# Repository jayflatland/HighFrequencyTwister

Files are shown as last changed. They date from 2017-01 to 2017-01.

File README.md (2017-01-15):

# HighFrequencyTwister
These are all the source code and design files for High Frequency Twister, the Rubik's Cube solving robot built by Jay Flatland and Paul Rose that set the World Record at 0.900s on February 5, 2016.

Primary files include:
* FreeCAD drawings for 3D printed parts
* Arduino sketch for stepper motor controller
* C++ code for the solving application
* Various other cruft we collected along the way

The code is a mess, but it got the job done.  We meant to organize this better before releasing, but never got around to it and decided to just publish it as-is rather than delaying any more.

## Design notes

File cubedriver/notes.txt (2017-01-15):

ThreadSolver2 - nkclintrade, goal 887ms, target 887ms, speed 5 (more), 8 threads, 0,LR90,FB90,D1,L1,R1,L3,B3,B1,F1,D3,U3,U1,R3,F3,F2,D2,R2,L2,B2,U2
Runs: 1000
Fails: 0
avgSolveTime:    40.488ms
avgMovesTime:   797.816ms
avgTotalTime:   838.304ms
WithCamTime:    898.304ms
movesTimeHistogram:
600,32,3%
700,428,43%
800,534,53%
900,6,1%
underGoalHistogram: 887ms
0,355,36%
1000,645,64%
solutionIdxHistogram:
0,208,21%
1,211,21%
2,216,22%
3,97,10%
4,76,8%
5,50,5%
6,69,7%
7,73,7%

ThreadSolver2 - nkclintrade, goal 887ms, target 887ms, speed 5, 8 threads, 0,LR90,FB90,D1,L1,R1,L3,B3,B1,F1,D3,U3,U1,R3,F3,F2,D2,R2,L2,B2,U2
Runs: 1000
Fails: 0
avgSolveTime:    40.928ms
avgMovesTime:   823.402ms
avgTotalTime:   864.330ms
WithCamTime:    924.330ms
movesTimeHistogram:
600,18,2%
700,292,29%
800,659,66%
900,31,3%
underGoalHistogram: 887ms
0,201,20%
1000,799,80%
solutionIdxHistogram:
0,208,21%
1,211,21%
2,216,22%
3,97,10%
4,76,8%
5,50,5%
6,69,7%
7,73,7%

ThreadSolver2 - nkclintrade, goal 887ms, target 887ms, speed 4, 8 threads, 0,LR90,FB90,D1,L1,R1,L3,B3,B1,F1,D3,U3,U1,R3,F3,F2,D2,R2,L2,B2,U2
Runs: 1000
Fails: 0
avgSolveTime:    40.722ms
avgMovesTime:   859.545ms
avgTotalTime:   900.267ms
WithCamTime:    960.267ms
movesTimeHistogram:
600,5,0%
700,120,12%
800,656,66%
900,219,22%
underGoalHistogram: 887ms
0,129,13%
1000,871,87%
solutionIdxHistogram:
0,211,21%
1,215,22%
2,212,21%
3,97,10%
4,72,7%
5,51,5%
6,69,7%
7,73,7%

ThreadSolver2 - nkclintrade, goal 887ms, target 850ms, speed 4, 8 threads, 0,LR90,FB90,D1,L1,R1,L3,B3,B1,F1,D3,U3,U1,R3,F3,F2,D2,R2,L2,B2,U2
Runs: 1000
Fails: 0
avgSolveTime:    40.572ms
avgMovesTime:   859.194ms
avgTotalTime:   899.766ms
WithCamTime:    959.766ms
movesTimeHistogram:
600,5,0%
700,123,12%
800,653,65%
900,219,22%
underGoalHistogram: 887ms
0,92,9%
1000,908,91%
solutionIdxHistogram:
0,208,21%
1,211,21%
2,214,21%
3,98,10%
4,77,8%
5,50,5%
6,69,7%
7,73,7%

ThreadSolver2 - nkclintrade, goal 887ms, target 850ms, speed 4, 4 threads, 0,LR90,FB90,D1,L1,R1,L3,B3,B1,F1,D3,U3,U1,R3,F3,F2,D2,R2,L2,B2,U2
Runs: 1000
Fails: 0
avgSolveTime:    29.807ms
avgMovesTime:   873.162ms
avgTotalTime:   902.969ms
WithCamTime:    962.969ms
movesTimeHistogram:
600,3,0%
700,98,10%
800,564,56%
900,328,33%
1000,7,1%
underGoalHistogram: 887ms
0,97,10%
1000,903,90%
solutionIdxHistogram:
0,294,29%
1,285,28%
2,299,30%
3,122,12%

ThreadSolver2 - nkclintrade, goal 887ms, target 800ms, speed 4, 4 threads, 0,LR90,FB90,D1,L1,R1,L3,B3,B1,F1,D3,U3,U1,R3,F3,F2,D2,R2,L2,B2,U2
Runs: 1000
Fails: 0
avgSolveTime:    29.822ms
avgMovesTime:   873.120ms
avgTotalTime:   902.942ms
WithCamTime:    962.942ms
movesTimeHistogram:
600,3,0%
700,98,10%
800,564,56%
900,328,33%
1000,7,1%
underGoalHistogram: 887ms
0,99,10%
1000,901,90%
solutionIdxHistogram:
0,293,29%
1,285,28%
2,300,30%
3,122,12%

ThreadSolver2 - nkclintrade, goal 887ms, target 100ms, speed 4, 4 threads, 0,LR90,FB90,D1,L1,R1,L3,B3,B1,F1,D3,U3,U1,R3,F3,F2,D2,R2,L2,B2,U2
Runs: 1000
Fails: 0
avgSolveTime:    29.509ms
avgMovesTime:   873.120ms
avgTotalTime:   902.629ms
WithCamTime:    962.629ms
movesTimeHistogram:
600,3,0%
700,98,10%
800,564,56%
900,328,33%
1000,7,1%
underGoalHistogram: 887ms
0,99,10%
1000,901,90%
solutionIdxHistogram:
0,293,29%
1,285,28%
2,300,30%
3,122,12%

ThreadSolver2 - nkclintrade, goal 887ms, target 100ms, speed 4, 8 threads, 0,LR90,FB90,D1,L1,R1,L3,B3,B1,F1,D3,U3,U1,R3,F3,F2,D2,R2,L2,B2,U2
Runs: 1000
Fails: 0
avgSolveTime:    40.834ms
avgMovesTime:   859.152ms
avgTotalTime:   899.986ms
WithCamTime:    959.986ms
movesTimeHistogram:
600,5,0%
700,123,12%
800,653,65%
900,219,22%
underGoalHistogram: 887ms
0,92,9%
1000,908,91%
solutionIdxHistogram:
0,208,21%
1,211,21%
2,215,22%
3,98,10%
4,76,8%
5,50,5%
6,69,7%
7,73,7%

ThreadSolver2 - nkclintrade, target 850ms, speed 4, 3 threads, 0,LR90,FB90
Runs: 1000
Fails: 0
avgSolveTime:    26.048ms
avgMovesTime:   879.837ms
avgTotalTime:   905.885ms
WithCamTime:    965.885ms
movesTimeHistogram:
600,3,0%
700,86,9%
800,517,52%
900,382,38%
1000,12,1%
underGoalHistogram: 887ms
0,108,11%
1000,892,89%
solutionIdxHistogram:
0,340,34%
1,329,33%
2,331,33%

ThreadSolver2 - nkclintrade, target 850ms, speed 4, 4 threads, 0,LR90,FB90,D1
Runs: 1000
Fails: 0
avgSolveTime:    29.391ms
avgMovesTime:   873.489ms
avgTotalTime:   902.880ms
WithCamTime:    962.880ms
movesTimeHistogram:
600,3,0%
700,94,9%
800,568,57%
900,328,33%
1000,7,1%
underGoalHistogram: 887ms
0,117,12%
1000,883,88%
solutionIdxHistogram:
0,300,30%
1,285,28%
2,295,30%
3,120,12%

ThreadSolver2 - nkclintrade, target 850ms, speed 4, 8 threads, 0,LR90,FB90,D1,L1,R1,L3,B3
Runs: 1000
Fails: 0
avgSolveTime:    40.872ms
avgMovesTime:   859.923ms
avgTotalTime:   900.795ms
WithCamTime:    960.795ms
movesTimeHistogram:
600,5,0%
700,114,11%
800,662,66%
900,219,22%
underGoalHistogram: 887ms
0,118,12%
1000,882,88%
solutionIdxHistogram:
0,216,22%
1,215,22%
2,212,21%
3,95,10%
4,73,7%
5,50,5%
6,67,7%
7,72,7%

ThreadSolver2 - nkclintrade, target 980ms, 8 threads, 0,LR90,FB90,D1,L1,R1,L3,B3
Runs: 1000
Fails: 0
avgSolveTime:    40.933ms
avgMovesTime:   893.387ms
avgTotalTime:   934.320ms
WithCamTime:    994.320ms
movesTimeHistogram:
700,48,5%
800,438,44%
900,507,51%
1000,7,1%
under1SecHistogram:
0,492,49%
1000,508,51%
solutionIdxHistogram:
0,239,24%
1,220,22%
2,212,21%
3,85,8%
4,72,7%
5,48,5%
6,57,6%
7,67,7%

ThreadSolver2 - nkclintrade, 8 threads, 0,LR90,FB90,D1,L1,R1,L3,B3
Runs: 1000
Fails: 0
avgSolveTime:    40.752ms
avgMovesTime:   897.303ms
avgTotalTime:   938.055ms
WithCamTime:    998.055ms
movesTimeHistogram:
700,36,4%
800,409,41%
900,548,55%
1000,7,1%
under1SecHistogram:
0,507,51%
1000,493,49%
solutionIdxHistogram:
0,267,27%
1,233,23%
2,193,19%
3,83,8%
4,64,6%
5,48,5%
6,49,5%
7,63,6%

ThreadSolver2 - nkclintrade, 4 threads, 0,LR90,FB90,D1
Runs: 1000
Fails: 0
avgSolveTime:    29.523ms
avgMovesTime:   910.362ms
avgTotalTime:   939.885ms
WithCamTime:    999.885ms
movesTimeHistogram:
700,35,4%
800,332,33%
900,590,59%
1000,43,4%
under1SecHistogram:
0,483,48%
1000,517,52%
solutionIdxHistogram:
0,353,35%
1,287,29%
2,258,26%
3,102,10%

ThreadSolver2 - nkclintrade, 9 threads, 0,LR90,FB90,D1,L1,R1,L3,B3,B1
Runs: 1000
Fails: 0
avgSolveTime:    43.563ms
avgMovesTime:   894.752ms
avgTotalTime:   938.315ms
WithCamTime:    998.315ms
movesTimeHistogram:
700,39,4%
800,426,43%
900,531,53%
1000,4,0%
under1SecHistogram:
0,504,50%
1000,496,50%
solutionIdxHistogram:
0,261,26%
1,221,22%
2,184,18%
3,75,8%
4,65,6%
5,44,4%
6,48,5%
7,59,6%
8,43,4%

ThreadSolver2 - nkclintrade, 11 threads, 0,LR90,FB90,D1,L1,R1,L3,B3,B1,F1,D3
Runs: 1000
Fails: 0
avgSolveTime:    48.625ms
avgMovesTime:   891.979ms
avgTotalTime:   940.604ms
WithCamTime:   1000.604ms
movesTimeHistogram:
700,41,4%
800,454,45%
900,503,50%
1000,2,0%
under1SecHistogram:
0,503,50%
1000,497,50%
solutionIdxHistogram:
0,254,25%
1,208,21%
2,170,17%
3,68,7%
4,56,6%
5,43,4%
6,43,4%
7,54,5%
8,39,4%
9,31,3%
10,34,3%

ThreadSolver2 - nkclintrade, 21 threads, 0,LR90,FB90,D1,L1,R1,L3,B3,B1,F1,D3,U3,U1,R3,F3,F2,D2,R2,L2,B2,U2
Runs: 1000
Fails: 0
avgSolveTime:    72.310ms
avgMovesTime:   883.272ms
avgTotalTime:   955.582ms
WithCamTime:   1015.582ms
movesTimeHistogram:
600,1,0%
700,53,5%
800,525,52%
900,420,42%
1000,1,0%
under1SecHistogram:
0,435,44%
1000,565,56%
solutionIdxHistogram:
0,215,22%
1,165,16%
2,161,16%
3,63,6%
4,51,5%
5,30,3%
6,40,4%
7,45,4%
8,35,4%
9,29,3%
10,28,3%
11,19,2%
12,15,2%
13,16,2%
14,21,2%
15,13,1%
16,19,2%
17,6,1%
18,17,2%
19,10,1%
20,2,0%

ThreadSolver2 - nkclintrade, 11 threads, 0,LR_90,FB_90,D1,R1,L1,D3,B3,B1,U1,L3,
Runs: 1000
Fails: 0
avgSolveTime:    48.477ms
avgMovesTime:   892.187ms
avgTotalTime:   940.664ms
WithCamTime:   1000.664ms
movesTimeHistogram:
600,1,0%
700,41,4%
800,452,45%
900,504,50%
1000,2,0%
under1SecHistogram:
0,512,51%
1000,488,49%

ThreadSolver2 - nkclintrade, 11 threads, LR, FB, others
Runs: 1000
Fails: 0
avgSolveTime:    47.994ms
avgMovesTime:   892.265ms
avgTotalTime:   940.259ms
WithCamTime:   1000.259ms
movesTimeHistogram:
700,43,4%
800,450,45%
900,505,50%
1000,2,0%
under1SecHistogram:
0,511,51%
1000,489,49%
solutionIdxHistogram:
0,248,25%
1,211,21%
2,179,18%
3,68,7%
4,48,5%
5,56,6%
6,40,4%
7,54,5%
8,40,4%
9,16,2%
10,40,4%

ThreadSolver2 - nkclintrade, 12 threads, D1,R1,L1,D3,B3,B1,U1,L3,F1,F3,U3
Runs: 1000
Fails: 0
avgSolveTime:    48.648ms
avgMovesTime:   902.721ms
avgTotalTime:   951.369ms
WithCamTime:   1011.369ms
movesTimeHistogram:
600,1,0%
700,34,3%
800,369,37%
900,578,58%
1000,18,2%
under1SecHistogram:
0,426,43%
1000,574,57%

ThreadSolver2 - nkclintrade, 10 threads, D1,R1,L1,D3,B3,B1,U1,L3,F1
Runs: 1000
Fails: 0
avgSolveTime:    44.375ms
avgMovesTime:   905.439ms
avgTotalTime:   949.814ms
WithCamTime:   1009.814ms
movesTimeHistogram:
600,1,0%
700,33,3%
800,354,35%
900,588,59%
1000,24,2%
under1SecHistogram:
0,434,43%
1000,566,57%

ThreadSolver2 - nkclintrade, 8 threads, D1,R1,L1,D3,B3,B1,U1
Runs: 1000
Fails: 0
avgSolveTime:    39.335ms
avgMovesTime:   912.175ms
avgTotalTime:   951.510ms
WithCamTime:   1011.510ms
movesTimeHistogram:
600,1,0%
700,31,3%
800,315,32%
900,605,60%
1000,48,5%
under1SecHistogram:
0,427,43%
1000,573,57%

ThreadSolver2 - nkclintrade, 11 threads, D1,R1,L1,D3,B3,B1,U1,L3,F1,F3
Runs: 1000
Fails: 0
avgSolveTime:    47.129ms
avgMovesTime:   903.401ms
avgTotalTime:   950.530ms
WithCamTime:   1010.530ms
movesTimeHistogram:
600,1,0%
700,34,3%
800,365,36%
900,581,58%
1000,19,2%
under1SecHistogram:
0,438,44%
1000,562,56%

ThreadSolver2 - nkclintrade, 19 threads, D1,R1,L1,D3,B3,B1,U1,L3,F1,F3,U3,R3,L2,D2,R2,F2,B2,U2
Runs: 1000
Fails: 0
avgSolveTime:    65.871ms
avgMovesTime:   894.527ms
avgTotalTime:   960.398ms
WithCamTime:   1020.398ms
movesTimeHistogram:
600,1,0%
700,43,4%
800,430,43%
900,519,52%
1000,7,1%
under1SecHistogram:
0,403,40%
1000,597,60%

ThreadSolver2 - nkclintrade, 9 threads, D1,R1,L1,D3,B3,B1,U1,L3
Runs: 1000
Fails: 0
avgSolveTime:    41.630ms
avgMovesTime:   908.034ms
avgTotalTime:   949.664ms
WithCamTime:   1009.664ms
movesTimeHistogram:
600,1,0%
700,31,3%
800,341,34%
900,592,59%
1000,35,4%
under1SecHistogram:
0,441,44%
1000,559,56%

ThreadSolver2 - nkclintrade, 9 threads, U1,D1,U3,D3,U2,D2,R1,F1
Runs: 1000
Fails: 0
avgSolveTime:    39.600ms
avgMovesTime:   919.229ms
avgTotalTime:   958.829ms
WithCamTime:   1018.829ms
movesTimeHistogram:
600,2,0%
700,27,3%
800,277,28%
900,627,63%
1000,67,7%
under1SecHistogram:
0,386,39%
1000,614,61%

ThreadSolver2 - nkclintrade, 8 threads, U1,D1,U3,D3,R1,F1,L1,B1
Runs: 1000
Fails: 0
avgSolveTime:    40.969ms
avgMovesTime:   912.332ms
avgTotalTime:   953.301ms
WithCamTime:   1013.301ms
movesTimeHistogram:
600,1,0%
700,31,3%
800,320,32%
900,603,60%
1000,45,4%
under1SecHistogram:
0,421,42%
1000,579,58%

ThreadSolver2 - nkclintrade, 8 threads, R1,F1,L1,B1,R3,F3,L3,B3
Runs: 1000
Fails: 0
avgSolveTime:    41.820ms
avgMovesTime:   910.996ms
avgTotalTime:   952.816ms
WithCamTime:   1012.816ms
movesTimeHistogram:
700,31,3%
800,317,32%
900,621,62%
1000,31,3%
under1SecHistogram:
0,414,41%
1000,586,59%

ThreadSolver2 - 8 threads, 3,1,2 - nkclintrade
Runs: 1000
Fails: 0
avgSolveTime:    40.714ms
avgMovesTime:   914.271ms
avgTotalTime:   954.985ms
WithCamTime:   1014.985ms
movesTimeHistogram:
600,1,0%
700,31,3%
800,290,29%
900,634,63%
1000,44,4%
under1SecHistogram:
0,398,40%
1000,602,60%

ThreadSolver2 - 8 threads, 1,3,2 - nkclintrade
Runs: 1000
Fails: 0
avgSolveTime:    41.374ms
avgMovesTime:   913.162ms
avgTotalTime:   954.536ms
WithCamTime:   1014.536ms
movesTimeHistogram:
600,1,0%
700,30,3%
800,316,32%
900,608,61%
1000,45,4%
under1SecHistogram:
0,415,42%
1000,585,58%

ThreadSolver2 - 8 threads, 2,1,3 - nkclintrade
Runs: 1000
Fails: 0
avgSolveTime:    40.949ms
avgMovesTime:   924.465ms
avgTotalTime:   965.414ms
WithCamTime:   1025.414ms
movesTimeHistogram:
700,25,2%
800,248,25%
900,654,65%
1000,73,7%
under1SecHistogram:
0,350,35%
1000,650,65%

ThreadSolver2 - cleanup, 9 threads, speed 3 (was 4), early solve - nkclintrade
Runs: 1000
Fails: 0
avgSolveTime:    40.361ms
avgMovesTime:   916.011ms
avgTotalTime:   956.372ms
WithCamTime:   1016.372ms
movesTimeHistogram:
700,30,3%
800,290,29%
900,634,63%
1000,46,5%
under1SecHistogram:
0,402,40%
1000,598,60%

ThreadSolver2 - cleanup, 6 threads, speed 3 (was 4), early solve - nkclintrade
Runs: 1000
Fails: 0
avgSolveTime:    32.936ms
avgMovesTime:   925.451ms
avgTotalTime:   958.387ms
WithCamTime:   1018.387ms
movesTimeHistogram:
700,25,2%
800,253,25%
900,639,64%
1000,83,8%
under1SecHistogram:
0,385,38%
1000,615,62%

ThreadSolver2 - cleanup, 8 threads, speed 3 (was 4), early solve - nkclintrade
Runs: 1000
Fails: 0
avgSolveTime:    38.105ms
avgMovesTime:   917.737ms
avgTotalTime:   955.842ms
WithCamTime:   1015.842ms
movesTimeHistogram:
700,30,3%
800,277,28%
900,642,64%
1000,51,5%
under1SecHistogram:
0,401,40%
1000,599,60%

ThreadSolver2 - cleanup, 10 threads, speed 3 (was 4), early solve - nkclintrade
Runs: 1000
Fails: 0
avgSolveTime:    42.747ms
avgMovesTime:   914.168ms
avgTotalTime:   956.915ms
WithCamTime:   1016.915ms
movesTimeHistogram:
700,33,3%
800,297,30%
900,632,63%
1000,38,4%
under1SecHistogram:
0,394,39%
1000,606,61%

ThreadSolver2 - cleanup, 16 threads, speed 3 (was 4), early solve - nkclintrade
Runs: 1000
Fails: 0
avgSolveTime:    58.096ms
avgMovesTime:   902.688ms
avgTotalTime:   960.784ms
WithCamTime:   1020.784ms
movesTimeHistogram:
700,38,4%
800,364,36%
900,587,59%
1000,11,1%
under1SecHistogram:
0,368,37%
1000,632,63%

ThreadSolver2 - 11 threads, speed 3 (was 4), early solve - nkclintrade
Runs: 1000
Fails: 0
avgSolveTime:    43.991ms
avgMovesTime:   911.506ms
avgTotalTime:   955.497ms
WithCamTime:   1015.497ms
movesTimeHistogram:
600,1,0%
700,34,3%
800,310,31%
900,623,62%
1000,32,3%
under1SecHistogram:
0,433,43%
1000,567,57%

Runs: 1000
Fails: 0
avgSolveTime:    43.573ms
avgMovesTime:   911.314ms
avgTotalTime:   954.887ms
WithCamTime:   1014.887ms
movesTimeHistogram:
600,2,0%
700,34,3%
800,308,31%
900,624,62%
1000,32,3%
under1SecHistogram:
0,431,43%
1000,569,57%

ThreadSolver2 - 16 threads, speed 4, early solve - nkclintrade
Runs: 1000
Fails: 0
avgSolveTime:    56.031ms
avgMovesTime:   901.564ms
avgTotalTime:   957.595ms
WithCamTime:   1017.595ms
movesTimeHistogram:
600,1,0%
700,43,4%
800,371,37%
900,574,57%
1000,11,1%
under1SecHistogram:
0,417,42%
1000,583,58%

ThreadSolver2 - 10 threads, speed 4, early solve - nkclintrade
Runs: 1000
Fails: 0
avgSolveTime:    41.029ms
avgMovesTime:   913.737ms
avgTotalTime:   954.766ms
WithCamTime:   1014.766ms
movesTimeHistogram:
700,34,3%
800,301,30%
900,627,63%
1000,38,4%
under1SecHistogram:
0,429,43%
1000,571,57%

ThreadSolver2 - 12 threads, speed 4, early solve - nkclintrade
Fails: 0
avgSolveTime:    46.166ms
avgMovesTime:   909.277ms
avgTotalTime:   955.443ms
WithCamTime:   1015.443ms
movesTimeHistogram:
600,1,0%
700,36,4%
800,324,32%
900,612,61%
1000,27,3%
under1SecHistogram:
0,426,43%
1000,574,57%

ThreadSolver2 - 13 threads, speed 4, early solve - nkclintrade
Runs: 1000
Fails: 0
avgSolveTime:    48.941ms
avgMovesTime:   907.859ms
avgTotalTime:   956.800ms
WithCamTime:   1016.800ms
movesTimeHistogram:
600,1,0%
700,36,4%
800,334,33%
900,609,61%
1000,20,2%
under1SecHistogram:
0,424,42%
1000,576,58%

ThreadSolver2 - 15 threads, speed 4, early solve - nkclintrade
Runs: 1000
Fails: 0
avgSolveTime:    53.506ms
avgMovesTime:   904.399ms
avgTotalTime:   957.905ms
WithCamTime:   1017.905ms
movesTimeHistogram:
600,1,0%
700,39,4%
800,351,35%
900,593,59%
1000,16,2%
under1SecHistogram:
0,410,41%
1000,590,59%

ThreadSolver2 - 4 threads, speed 4, early solve - nkclintrade
Runs: 1000
Fails: 0
avgSolveTime:    25.354ms
avgMovesTime:   942.984ms
avgTotalTime:   968.338ms
WithCamTime:   1028.338ms
movesTimeHistogram:
700,19,2%
800,192,19%
900,598,60%
1000,189,19%
1100,2,0%
under1SecHistogram:
0,332,33%
1000,668,67%

ThreadSolver2 - 8 threads, speed 4, early solve - nkclintrade
Runs: 1000
Fails: 0
avgSolveTime:    36.646ms
avgMovesTime:   917.523ms
avgTotalTime:   954.169ms
WithCamTime:   1014.169ms
movesTimeHistogram:
700,30,3%
800,281,28%
900,638,64%
1000,51,5%
under1SecHistogram:
0,420,42%
1000,580,58%

Standard test:
Runs: 1000
Fails: 0
avgSolveTime:    13.113ms
avgMovesTime:  1026.312ms
avgTotalTime:  1039.425ms
WithCamTime:   1099.425ms
movesTimeHistogram:
700,1,0%
800,53,5%
900,292,29%
1000,491,49%
1100,158,16%
1200,5,0%
under1SecHistogram:
0,128,13%
1000,872,87%

ThreadSolver2 - 16 threads, speed 4, early solve - nkclinjrf
Runs: 1000
Fails: 0
avgSolveTime:    56.486ms
avgMovesTime:   901.998ms
avgTotalTime:   958.484ms
WithCamTime:   1018.484ms
movesTimeHistogram:
600,1,0%
700,40,4%
800,370,37%
900,578,58%
1000,11,1%
under1SecHistogram:
0,402,40%
1000,598,60%

ThreadSolver2 - 16 threads, speed 4 - nkclinjrf
Runs: 1000
Fails: 0
avgSolveTime:    59.155ms
avgMovesTime:   897.838ms
avgTotalTime:   956.993ms
WithCamTime:   1016.993ms
movesTimeHistogram:
600,3,0%
700,52,5%
800,386,39%
900,548,55%
1000,11,1%
under1SecHistogram:
0,378,38%
1000,622,62%

ThreadSolver2 - 16 threads - nkclinjrf
Runs: 1000
Fails: 0
avgSolveTime:    59.284ms
avgMovesTime:   941.701ms
avgTotalTime:  1000.985ms
WithCamTime:   1060.985ms
movesTimeHistogram:
700,16,2%
800,168,17%
900,688,69%
1000,128,13%
under1SecHistogram:
0,176,18%
1000,824,82%

ThreadSolver2 - 16 threads - nkclintrade
Runs: 1000
Fails: 0
avgSolveTime:    58.014ms
avgMovesTime:   941.701ms
avgTotalTime:   999.715ms
WithCamTime:   1059.715ms
movesTimeHistogram:
700,16,2%
800,168,17%
900,688,69%
1000,128,13%
under1SecHistogram:
0,181,18%
1000,819,82%

ThreadSolver2 - 6 threads - devlab01
Runs: 1000
Fails: 0
avgSolveTime:    65.733ms
avgMovesTime:   931.294ms
avgTotalTime:   997.027ms
WithCamTime:   1057.027ms
movesTimeHistogram:
600,1,0%
700,26,3%
800,276,28%
900,549,55%
1000,148,15%
under1SecHistogram:
0,236,24%
1000,764,76%

ThreadSolver2 - 12 threads - devlab04
Runs: 1000
Fails: 0
avgSolveTime:   144.278ms
avgMovesTime:   914.277ms
avgTotalTime:  1058.555ms
WithCamTime:   1118.555ms
movesTimeHistogram:
600,1,0%
700,40,4%
800,344,34%
900,548,55%
1000,67,7%
under1SecHistogram:
0,129,13%
1000,871,87%

ThreadSolver2 - 16 threads - nkclinjrf
Runs: 1000
Fails: 0
avgSolveTime:    57.637ms
avgMovesTime:   902.499ms
avgTotalTime:   960.136ms
WithCamTime:   1020.136ms
movesTimeHistogram:
600,2,0%
700,49,5%
800,413,41%
900,511,51%
1000,25,2%
under1SecHistogram:
0,373,37%
1000,627,63%

ThreadSolver2 - 19 threads
Runs: 1000
Fails: 0
avgSolveTime:    65.582ms
avgMovesTime:   895.102ms
avgTotalTime:   960.684ms
WithCamTime:   1020.684ms
movesTimeHistogram:
600,2,0%
700,60,6%
800,459,46%
900,463,46%
1000,16,2%
under1SecHistogram:
0,380,38%
1000,620,62%

ThreadSolver2 - 13 threads
Runs: 1000
Fails: 0
avgSolveTime:    49.773ms
avgMovesTime:   911.963ms
avgTotalTime:   961.736ms
WithCamTime:   1021.736ms
movesTimeHistogram:
600,1,0%
700,41,4%
800,362,36%
900,539,54%
1000,57,6%
under1SecHistogram:
0,357,36%
1000,643,64%

ThreadSolver2 - 4 threads
Runs: 1000
Fails: 0
avgSolveTime:    27.148ms
avgMovesTime:   940.342ms
avgTotalTime:   967.490ms
WithCamTime:   1027.490ms
movesTimeHistogram:
600,1,0%
700,23,2%
800,239,24%
900,530,53%
1000,206,21%
1100,1,0%
under1SecHistogram:
0,330,33%
1000,670,67%

        { 24, 1000, "" },
Runs: 1000
Fails: 0
avgSolveTime:    15.422ms
avgMovesTime:   988.000ms
avgTotalTime:  1003.422ms
WithCamTime:   1063.422ms
movesTimeHistogram:
700,8,1%
800,126,13%
900,381,38%
1000,424,42%
1100,61,6%
under1SecHistogram:
0,207,21%
1000,793,79%

//19 threads
        { 24, 1000, "" },
        { 24, 1000, "U" },
        { 24, 1000, "R" },
        { 24, 1000, "F" },
        { 24, 1000, "D" },
        { 24, 1000, "L" },
        { 24, 1000, "B" },
        { 24, 1000, "U'" },
        { 24, 1000, "R'" },
        { 24, 1000, "F'" },
        { 24, 1000, "D'" },
        { 24, 1000, "L'" },
        { 24, 1000, "B'" },
        { 24, 1000, "U2" },
        { 24, 1000, "R2" },
        { 24, 1000, "F2" },
        { 24, 1000, "D2" },
        { 24, 1000, "L2" },
        { 24, 1000, "B2" },
Runs: 1000
Fails: 0
avgSolveTime:    81.659ms
avgMovesTime:   896.584ms
avgTotalTime:   978.243ms
WithCamTime:   1038.243ms
movesTimeHistogram:
600,2,0%
700,48,5%
800,466,47%
900,468,47%
1000,16,2%
under1SecHistogram:
0,279,28%
1000,721,72%

//13 threads
        { 24, 1000, "" },
        { 24, 1000, "U" },
        { 24, 1000, "R" },
        { 24, 1000, "F" },
        { 24, 1000, "D" },
        { 24, 1000, "L" },
        { 24, 1000, "B" },
        { 24, 1000, "U'" },
        { 24, 1000, "R'" },
        { 24, 1000, "F'" },
        { 24, 1000, "D'" },
        { 24, 1000, "L'" },
        { 24, 1000, "B'" },
Runs: 1000
Fails: 0
avgSolveTime:    64.674ms
avgMovesTime:   903.279ms
avgTotalTime:   967.953ms
WithCamTime:   1027.953ms
movesTimeHistogram:
600,2,0%
700,41,4%
800,424,42%
900,504,50%
1000,29,3%
under1SecHistogram:
0,325,32%
1000,675,68%

        { 24, 1000, "" },
        { 24, 1000, "U" },
        { 24, 1000, "R" },
        { 24, 1000, "F" },
        { 24, 1000, "D" },
        { 24, 1000, "L" },
        { 24, 1000, "B" },
        { 24, 1000, "U'" },
        { 24, 1000, "R'" },
Runs: 1000
Fails: 0
avgSolveTime:    53.675ms
avgMovesTime:   918.125ms
avgTotalTime:   971.800ms
WithCamTime:   1031.800ms
movesTimeHistogram:
600,1,0%
700,26,3%
800,351,35%
900,550,55%
1000,72,7%
under1SecHistogram:
0,321,32%
1000,679,68%

        { 24, 1000, "" },
        { 24, 1000, "U" },
        { 24, 1000, "R" },
        { 24, 1000, "F" },
        { 24, 1000, "D" },
        { 24, 1000, "L" },
        { 24, 1000, "B" },
        { 24, 1000, "U'" },
Runs: 1000
Fails: 0
avgSolveTime:    49.526ms
avgMovesTime:   920.881ms
avgTotalTime:   970.407ms
WithCamTime:   1030.407ms
movesTimeHistogram:
600,1,0%
700,24,2%
800,334,33%
900,559,56%
1000,82,8%
under1SecHistogram:
0,319,32%
1000,681,68%

        { 24, 1000, "" },
        { 24, 1000, "U" },
        { 24, 1000, "R" },
        { 24, 1000, "F" },
        { 24, 1000, "D" },
        { 24, 1000, "L" },
        { 24, 1000, "B" },
Runs: 1000
Fails: 0
avgSolveTime:    48.311ms
avgMovesTime:   922.727ms
avgTotalTime:   971.038ms
WithCamTime:   1031.038ms
movesTimeHistogram:
600,1,0%
700,24,2%
800,322,32%
900,562,56%
1000,91,9%
under1SecHistogram:
0,315,32%
1000,685,68%

        { 24, 1000, "" },
        { 24, 1000, "U" },
        { 24, 1000, "R" },
        { 24, 1000, "F" },
Runs: 1000
Fails: 0
avgSolveTime:    37.230ms
avgMovesTime:   950.456ms
avgTotalTime:   987.686ms
WithCamTime:   1047.686ms
movesTimeHistogram:
600,1,0%
700,13,1%
800,204,20%
900,537,54%
1000,242,24%
1100,3,0%
under1SecHistogram:
0,239,24%
1000,761,76%

        { 24, 1000, "" },
        { 24, 1000, "U" },
        { 24, 1000, "R" },
        { 24, 1000, "F" },
        { 24, 1000, "D" },
        { 24, 1000, "L" },
        { 24, 1000, "B" },
Runs: 1000
Fails: 0
avgSolveTime:    58.232ms
avgMovesTime:   922.727ms
avgTotalTime:   980.959ms
WithCamTime:   1040.959ms
movesTimeHistogram:
600,1,0%
700,24,2%
800,322,32%
900,562,56%
1000,91,9%
under1SecHistogram:
0,273,27%
1000,727,73%

1 thread, standard
Runs: 1000
Fails: 0
avgSolveTime:    13.188ms
avgMovesTime:   940.422ms
avgTotalTime:   953.610ms
WithCamTime:   1013.610ms
movesTimeHistogram:
700,28,3%
800,223,22%
900,544,54%
1000,197,20%
1100,8,1%
under1SecHistogram:
0,413,41%
1000,587,59%

3 threads, standard, R1, and U1
Runs: 1000
Fails: 0
avgSolveTime:    26.731ms
avgMovesTime:   904.467ms
avgTotalTime:   931.198ms
WithCamTime:    991.198ms
movesTimeHistogram:
600,1,0%
700,46,5%
800,362,36%
900,545,54%
1000,46,5%
under1SecHistogram:
0,535,54%
1000,465,46%

4 threads, standard, R1, R2, and R3 (no better)
Runs: 1000
Fails: 0
avgSolveTime:    30.733ms
avgMovesTime:   910.114ms
avgTotalTime:   940.847ms
WithCamTime:   1000.847ms
movesTimeHistogram:
700,37,4%
800,334,33%
900,574,57%
1000,54,5%
1100,1,0%
under1SecHistogram:
0,473,47%
1000,527,53%

3 threads, standard, R1, and R3 (no better)
Runs: 1000
Fails: 0
avgSolveTime:    24.577ms
avgMovesTime:   914.978ms
avgTotalTime:   939.555ms
WithCamTime:    999.555ms
movesTimeHistogram:
700,36,4%
800,312,31%
900,577,58%
1000,74,7%
1100,1,0%
under1SecHistogram:
0,483,48%
1000,517,52%

Threading baseline (home)
        {24,1000},
Runs: 1000
Fails: 0
avgSolveTime:    13.133ms
avgMovesTime:   940.422ms
avgTotalTime:   953.555ms
WithCamTime:   1013.555ms
movesTimeHistogram:
700,28,3%
800,223,22%
900,544,54%
1000,197,20%
1100,8,1%
under1SecHistogram:
0,415,42%
1000,585,58%

        {23, 1000},
Runs: 1000
Fails: 0
avgSolveTime:    12.796ms
avgMovesTime:   940.422ms
avgTotalTime:   953.218ms
WithCamTime:   1013.218ms
movesTimeHistogram:
700,28,3%
800,223,22%
900,544,54%
1000,197,20%
1100,8,1%
under1SecHistogram:
0,414,41%
1000,586,59%

        {21,  20},
        {22,  30},
        {23,  40},
        {24,1000},
Runs: 1000
Fails: 0
avgSolveTime:    18.806ms
avgMovesTime:   940.273ms
avgTotalTime:   959.079ms
WithCamTime:   1019.079ms
movesTimeHistogram:
700,28,3%
800,224,22%
900,543,54%
1000,197,20%
1100,8,1%
under1SecHistogram:
0,396,40%
1000,604,60%

        {20,  70},
        {21,  70},
        {22,  80},
        {23,  90},
        {24,1000},
Runs: 1000
Fails: 0
avgSolveTime:    45.195ms
avgMovesTime:   926.105ms
avgTotalTime:   971.300ms
WithCamTime:   1031.300ms
movesTimeHistogram:
700,44,4%
800,291,29%
900,506,51%
1000,153,15%
1100,6,1%
under1SecHistogram:
0,378,38%
1000,622,62%

        {21,  70},
        {22,  80},
        {23,  90},
        {24,1000},
Runs: 1000
Fails: 0
avgSolveTime:    22.795ms
avgMovesTime:   938.799ms
avgTotalTime:   961.594ms
WithCamTime:   1021.594ms
movesTimeHistogram:
700,28,3%
800,229,23%
900,548,55%
1000,188,19%
1100,7,1%
under1SecHistogram:
0,392,39%
1000,608,61%

Some threads
        {20,  40},
        {21,  60},
        {22,  80},
        {23, 100},
        {24,1000},
Runs: 1000
Fails: 0
avgSolveTime:    32.701ms
avgMovesTime:   930.596ms
avgTotalTime:   963.297ms
WithCamTime:   1023.297ms
movesTimeHistogram:
700,38,4%
800,272,27%
900,520,52%
1000,164,16%
1100,6,1%
under1SecHistogram:
0,391,39%
1000,609,61%

        {20,  30},
        {21,  50},
        {22,  70},
        {23,  90},
        {24,1000},
Runs: 1000
Fails: 0
avgSolveTime:    27.937ms
avgMovesTime:   933.708ms
avgTotalTime:   961.645ms
WithCamTime:   1021.645ms
movesTimeHistogram:
700,35,4%
800,258,26%
900,524,52%
1000,177,18%
1100,6,1%
under1SecHistogram:
0,385,38%
1000,615,62%

Basic 24 Solve (no threads) - optimzation baseline
Runs: 1000
Fails: 0
avgSolveTime:    14.434ms
avgMovesTime:   940.422ms
avgTotalTime:   954.856ms
WithCamTime:   1014.856ms
movesTimeHistogram:
700,28,3%
800,223,22%
900,544,54%
1000,197,20%
1100,8,1%

        Single    Threaded
600     0,0%      2,0%
700     28,3%     60,6%
800     223,22%   318,32%
900     544,54%   466,47%
1000    197,20%   148,15%
1100    8,1%      6,1%

        {24,1000},
avgSolveTime:    12.450ms
avgMovesTime:   940.422ms
avgTotalTime:   952.872ms
WithCamTime:   1012.872ms
700,1,0%
800,72,7%
900,344,34%
1000,462,46%
1100,116,12%
1200,5,0%
[moves time]
700,28,3%
800,223,22%
900,544,54%
1000,197,20%
1100,8,1%

        {17, 100},
        {18, 100},
        {19, 100},
        {20, 100},
        {22, 100},
        {24,1000},
avgSolveTime:   100.945ms
avgMovesTime:   919.163ms
avgTotalTime:  1020.108ms
WithCamTime:   1080.108ms
[moves time]
600,2,0%
700,60,6%
800,318,32%
900,466,47%
1000,148,15%
1100,6,1%

        {17,  15},
        {20,  15},
        {24,1000},
avgSolveTime:    20.144ms
avgMovesTime:   937.501ms
avgTotalTime:   957.645ms
WithCamTime:   1017.645ms
700,3,0%
800,59,6%
900,315,32%
1000,490,49%
1100,128,13%
1200,5,0%

        {20,  50},
        {24,1000},
avgSolveTime:    32.080ms
avgMovesTime:   928.448ms
avgTotalTime:   960.528ms
WithCamTime:   1020.528ms
700,3,0%
800,82,8%
900,323,32%
1000,393,39%
1100,187,19%
1200,12,1%

        {19, 100},
        {24,1000},
avgSolveTime:    87.071ms
avgMovesTime:   930.362ms
avgTotalTime:  1017.433ms
WithCamTime:   1077.433ms
700,5,0%
800,54,5%
900,144,14%
1000,298,30%
1100,417,42%
1200,82,8%

        {17, 100},
        {18, 100},
        {19, 100},
        {20, 100},
        {21, 100},
        {22, 100},
        {23, 100},
        {24,1000},
Runs: 1000
Fails: 0
avgSolveTime:   123.846ms
avgMovesTime:   919.884ms
avgTotalTime:  1043.730ms
WithCamTime:   1103.730ms
700,2,0%
800,7,1%
900,88,9%
1000,372,37%
1100,427,43%
1200,103,10%
1300,1,0%

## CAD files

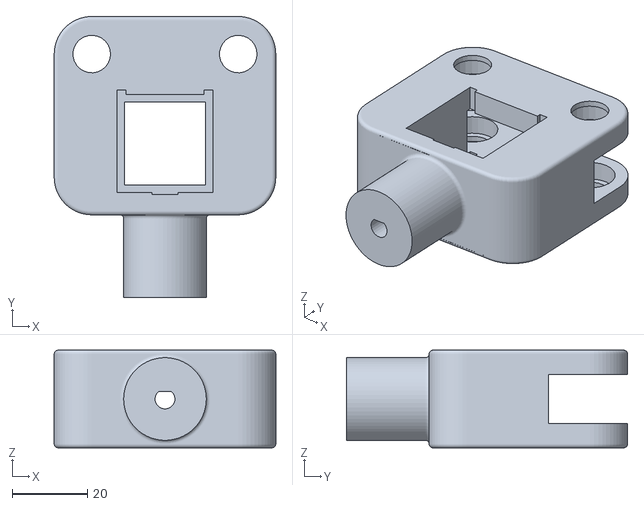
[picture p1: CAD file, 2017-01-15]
CAD Drawings/Phase 5 Claw/Claw5 - Main Body.stl
59.0 x 74.8 x 26.0

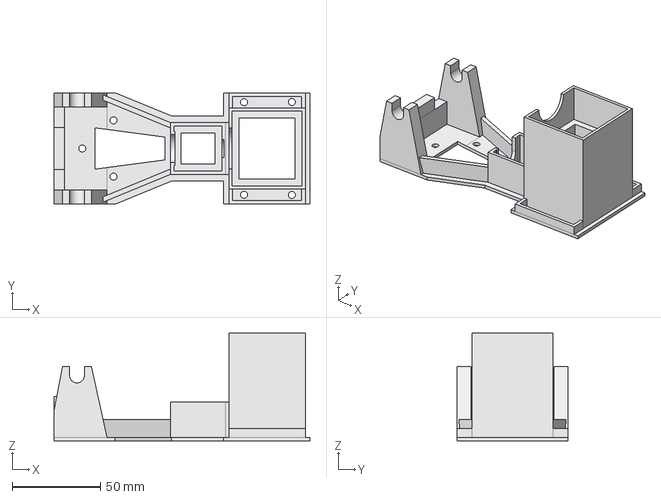
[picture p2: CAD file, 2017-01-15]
CAD Drawings/Phase 2 Speedster/Assembly Tray.FCStd
144.9 x 63.0 x 61.0 mm

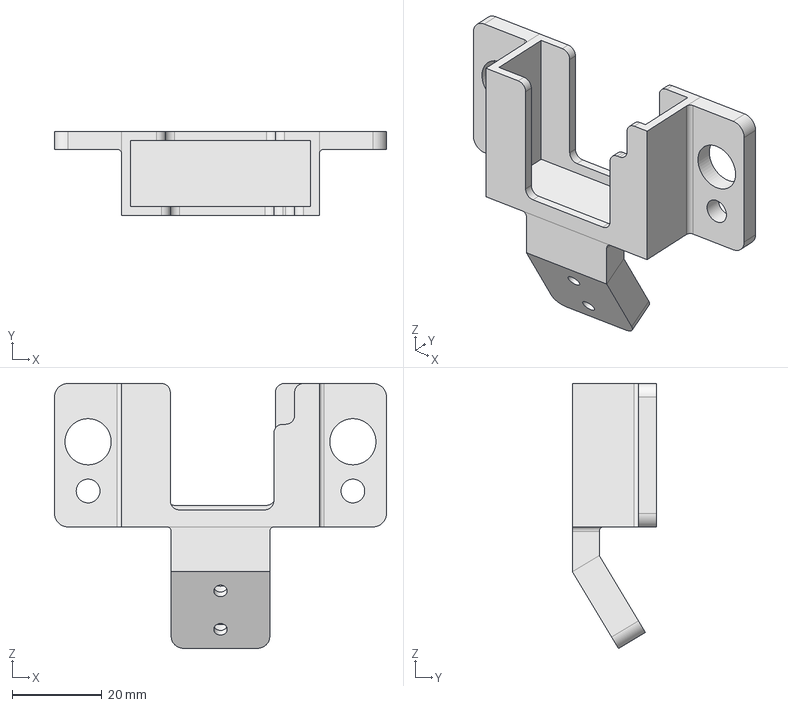
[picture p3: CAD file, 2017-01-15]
CAD Drawings/Camera Mounts/Upper Camera Mount.FCStd
74.1 x 18.8 x 59.1 mm

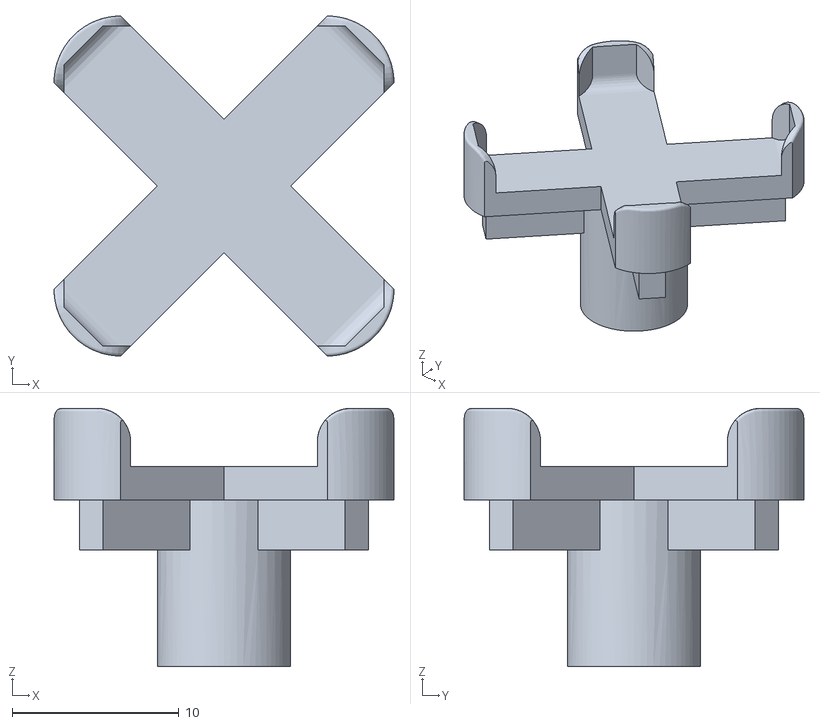
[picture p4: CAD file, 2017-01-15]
CAD Drawings/Phase 1 Prototype/Rubiks Center Square Foot 2 - Lego.stl
20.4 x 20.4 x 15.5

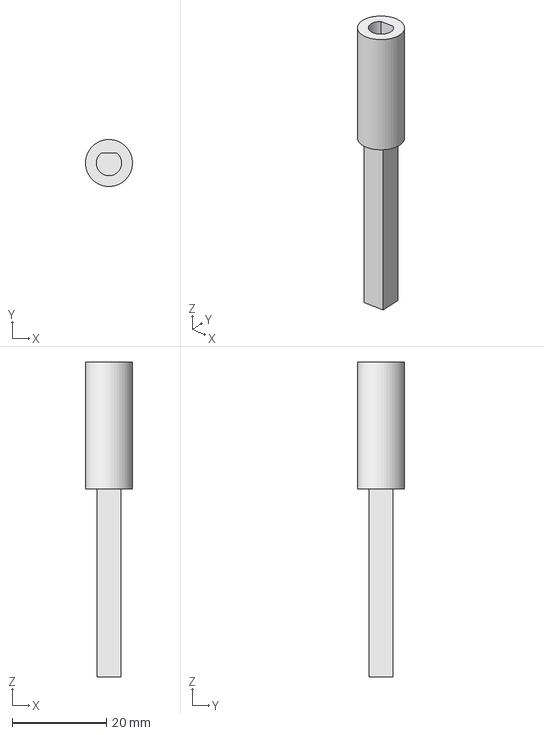
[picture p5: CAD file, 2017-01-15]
CAD Drawings/Phase 2 Speedster/Drive Shaft.FCStd
9.99 x 10.00 x 67.0 mm

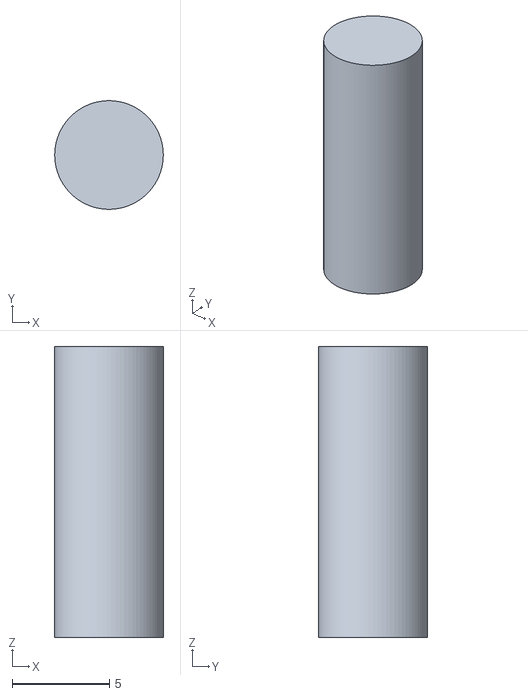
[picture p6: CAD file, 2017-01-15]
CAD Drawings/Phase 3 Claw/Claw 2 - Peg.stl
5.60 x 5.60 x 15.0

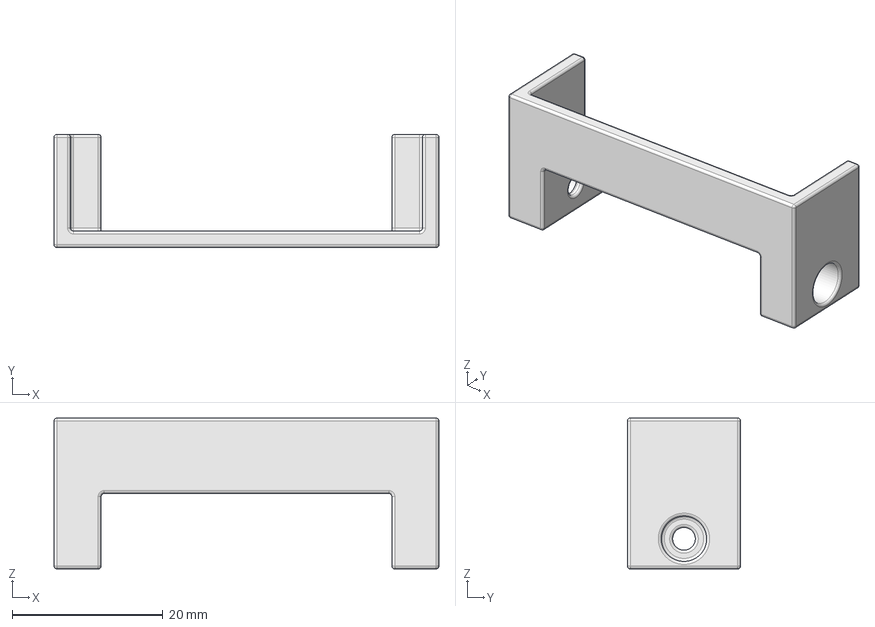
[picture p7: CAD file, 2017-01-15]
CAD Drawings/Camera Mounts/Machine Bracket.FCStd
51.0 x 15.0 x 20.0 mm

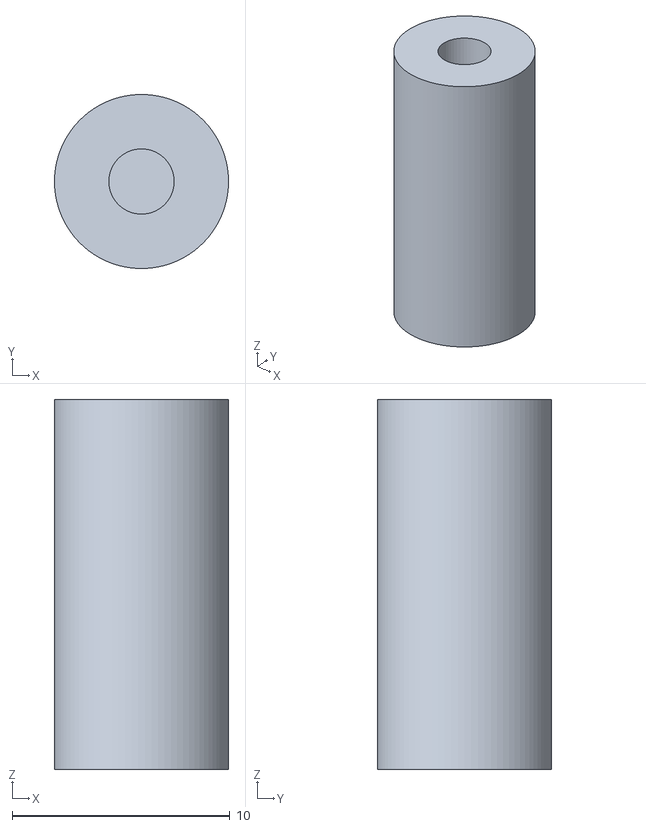
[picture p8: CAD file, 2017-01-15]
CAD Drawings/Phase 1 Prototype/Small Stepper Drive Shaft Test Knob - Lego.STL
8.00 x 7.99 x 17.0

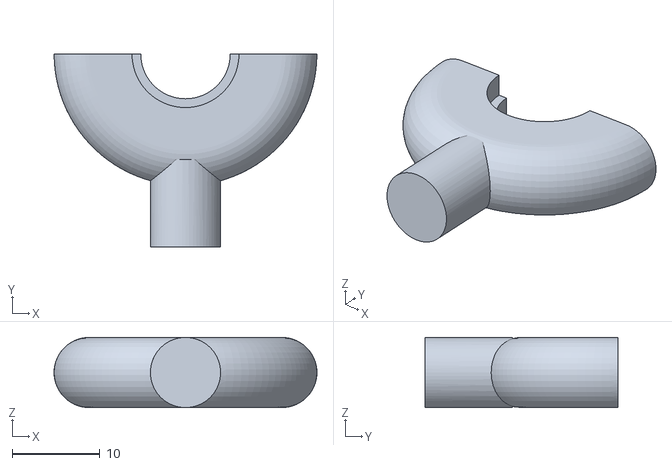
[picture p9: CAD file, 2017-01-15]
CAD Drawings/Phase 2 Speedster/Push Ring Top.stl
30.0 x 22.0 x 8.00

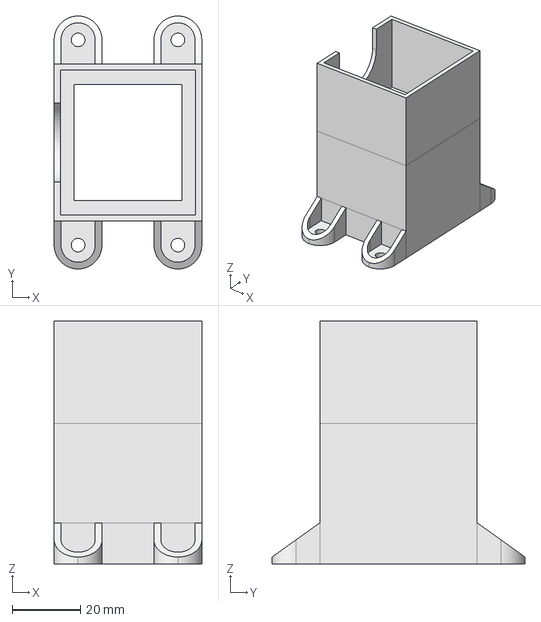
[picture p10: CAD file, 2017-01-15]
CAD Drawings/Phase 3 Claw/Motor Base.FCStd
43.2 x 74.0 x 71.0 mm

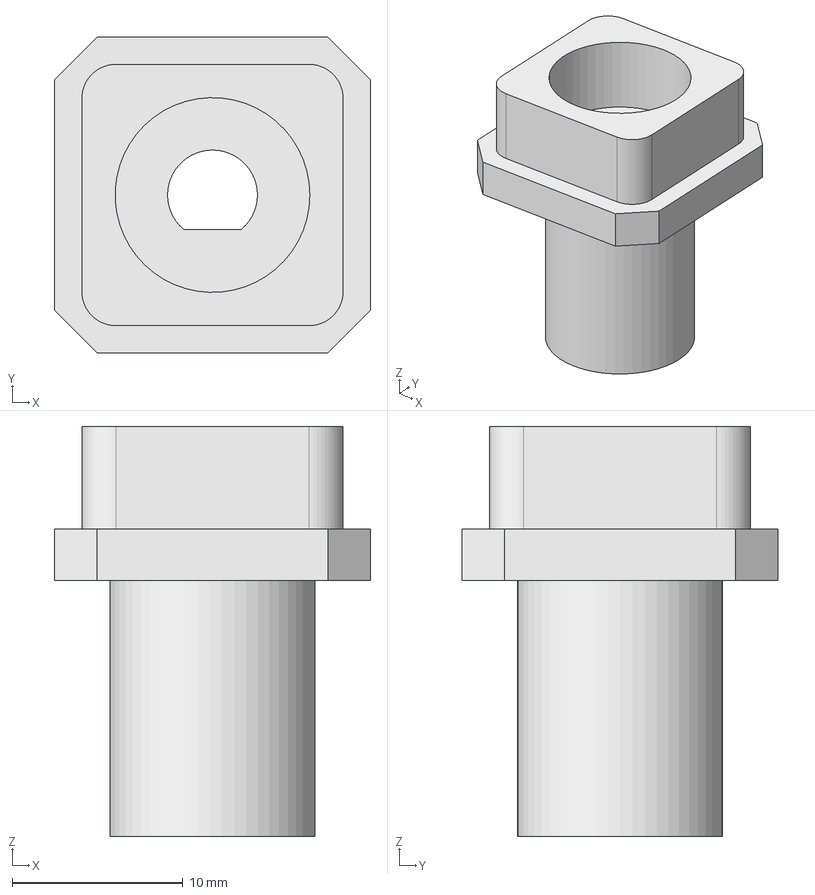
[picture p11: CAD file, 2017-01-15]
CAD Drawings/Phase 4 Center Drive Redux/Capless Drive.FCStd
18.5 x 18.5 x 24.0 mm

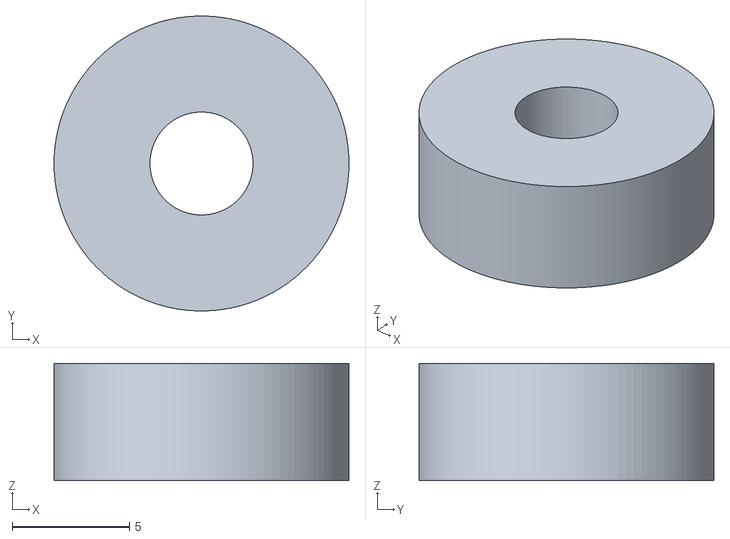
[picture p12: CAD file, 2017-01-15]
CAD Drawings/Phase 5 Claw/Claw5 - Test Bushing.stl
12.6 x 12.6 x 5.00

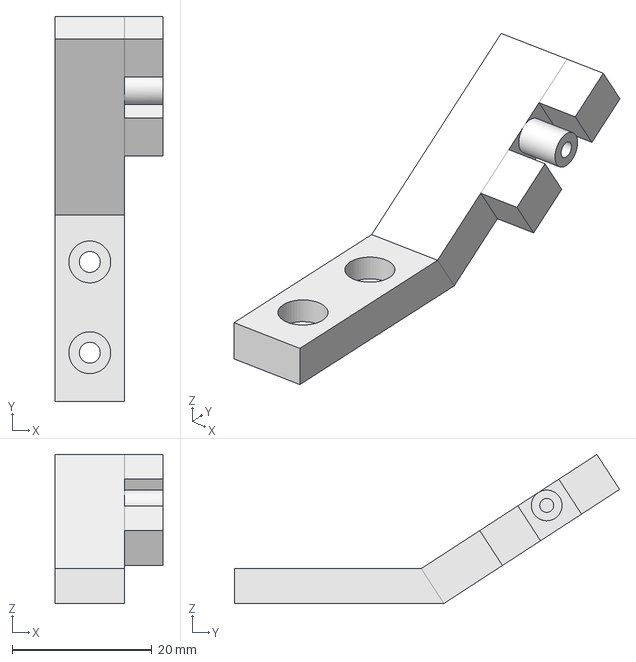
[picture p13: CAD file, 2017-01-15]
CAD Drawings/Camera Mounts/C310 Bracket.FCStd
15.5 x 55.2 x 21.3 mm

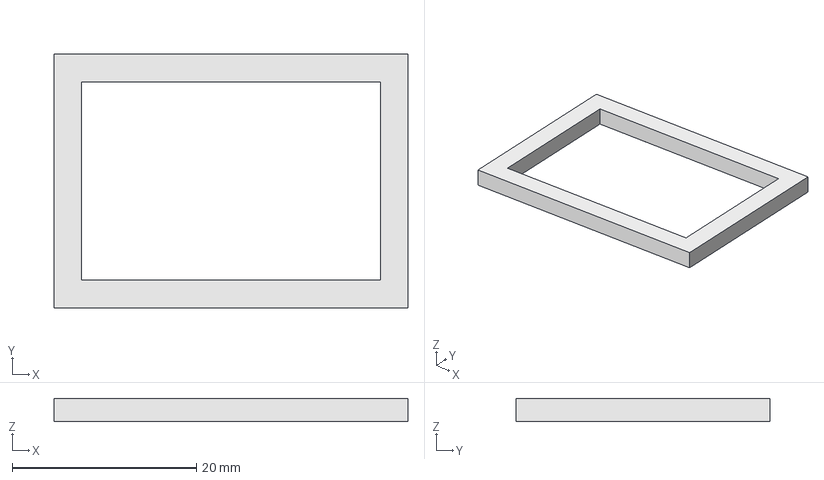
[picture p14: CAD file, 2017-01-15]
CAD Drawings/Phase 1 Prototype/Rubiks Frame Side Motor Shim.FCStd
38.4 x 27.5 x 2.50 mm

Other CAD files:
CAD Drawings/Phase 4 Center Drive Redux/Sixth Motor Frame 2.FCStd
CAD Drawings/Phase 2 Speedster/Fixed Claw.FCStd
CAD Drawings/Phase 3 Claw/Claw.FCStd
CAD Drawings/Phase 4 Center Drive Redux/Notched Center Square.FCStd
CAD Drawings/Camera Mounts/C310 Bracket.stl
CAD Drawings/Camera Mounts/Lower Camera Mount.FCStd
CAD Drawings/Camera Mounts/Lower Camera Mount.stl
CAD Drawings/Camera Mounts/Machine Bracket.stl
CAD Drawings/Camera Mounts/Upper Camera Mount.stl
CAD Drawings/Phase 1 Prototype/Rubiks Center Square Foot 2.FCStd
CAD Drawings/Phase 1 Prototype/Rubiks Center Square Foot 2.stl
CAD Drawings/Phase 1 Prototype/Rubiks Center Square Foot 3 - Capless Drive.FCStd
CAD Drawings/Phase 1 Prototype/Rubiks Center Square Foot 3 - Capless Drive.stl
CAD Drawings/Phase 1 Prototype/Rubiks Center Square Foot.FCStd
CAD Drawings/Phase 1 Prototype/Rubiks Center Square Foot.stl
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

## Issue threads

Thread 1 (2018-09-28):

Is there a BOM for your project?

xoxota99, 2018-09-28:
What motors / motor drivers did you use? what cameras? Thanks!

jayflatland, 2018-09-29:
Hi!  Not sure I wrote down BOM anywhere.

I've attached a screenshot of the motors and drivers I used.  I drove the
motors at around 30v so they could step faster.

Hope that helps!

Jay

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

EquipmentAgain, 2018-10-07:
Dear Jay.
May you send me any information about the motors you used in your robot?
Model \ Part N \ Manufacture.
If it will be an attacments, my E-mail Equipa@mail.ru address will be very convinient for this.

toughmanshawn, 2019-05-06:
Would you please be able to send me the list of parts you used too. Thank you. Email is toughmanshawn@hotmail.com

Closed 2018-10-10.

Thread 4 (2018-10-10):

Motor's data.

EquipmentAgain, 2018-10-10:
Dear Jay.
May you send me any information about the motors you used in your robot?
Model \ Part N \ Manufacture.
Or just a photo of the motor's label.
You can also use my E-mail: Equipa@mail.ru for your information.

Best Regards,
Sergey.

Nappiie5, 2018-11-22:
Dear Jayflatland,

I was intrigue by the speed of this robot. I am now trying to build an enhanced version of it.
Can you also send me the motor used in the video?
my Email is nopleepp@gmail.com
Thank you in advance

Sincerely
NAPPIIE

jayflatland, 2018-11-22:
Sure!  Motors were 45Ncm Nema 17 Stepper Motor 2A 4-wire.  Motor controllers were StepStick format that fit the RAMPS 1.4 3d printer system.  I used a 36v power supply because steppers need higher voltage to run faster and have good torque.

Closed 2018-11-22.

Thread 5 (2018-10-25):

Help! Can't get OpenCV to recognize colors?

xoxota99, 2018-10-25:
I Can't for the life of me get OpenCV to recognize the correct colors using the linalg.norm approach that you've got in your code. I've also tried euclidean distance, normalized euclidean, and CIE2000 colorspace (per http://hanzratech.in/2015/01/16/color-difference-between-2-colors-using-python.html ). The tiniest change in lighting makes "Orange" get detected as "White", or "Blue" get detected as "Yellow".

Any tips on how to cut down on the noise in color detection, and get a higher-confidence estimate out of OpenCV?

jayflatland, 2018-10-25:
That actually was a huge problem for us, something we dealt with by
calibrating immediately before each run.  We didn't come up with any great
robust solution.

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

xoxota99, 2018-10-25:
Ah. Glad to know it's not just me, at least :-)

Did you calibrate using a solved/known-state cube?

jayflatland, 2018-10-25:
Yep, calibrate with solved cube

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

Closed 2018-11-22.

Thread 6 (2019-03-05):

Help in cubedriver

Sanket-Mahamulkar, 2019-03-05:
Dear Jayflatland,
I am trying to build this project , I have already built all the files and executed the solver gui , but I can't see any data getting transmitted or the cube getting solved when pressed spacebar / F7 key ,rather only the timer starts. Can you please contact me. My email id is : smahamulkar1013@gmail.com .It will be really helpful if I got some help . Thankyou

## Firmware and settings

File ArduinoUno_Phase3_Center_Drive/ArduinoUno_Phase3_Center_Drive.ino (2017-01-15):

#ifdef ARDUINO_AVR_MEGA2560
#define PIN_F_DIR      55   //X
#define PIN_F_STEP     54
#define PIN_F_DISABLE  38

#define PIN_B_DIR      61   //Y
#define PIN_B_STEP     60
#define PIN_B_DISABLE  56

#define PIN_L_DIR      48   //Z
#define PIN_L_STEP     46
#define PIN_L_DISABLE  62

#define PIN_R_DIR      28   //E (E0)
#define PIN_R_STEP     26
#define PIN_R_DISABLE  24

#define PIN_D_DIR      34   //Q (E1)
#define PIN_D_STEP     36
#define PIN_D_DISABLE  30

#define PIN_U_DIR      45   //AUX
#define PIN_U_STEP     47
#define PIN_U_DISABLE  32


//from RAMPS code (for reference)
#define X_STEP_PIN         54
#define X_DIR_PIN          55
#define X_ENABLE_PIN       38
#define X_MIN_PIN           3
#define X_MAX_PIN           2

#define Y_STEP_PIN         60
#define Y_DIR_PIN          61
#define Y_ENABLE_PIN       56
#define Y_MIN_PIN          14
#define Y_MAX_PIN          15

#define Z_STEP_PIN         46
#define Z_DIR_PIN          48
#define Z_ENABLE_PIN       62
#define Z_MIN_PIN          18
#define Z_MAX_PIN          19

#define E_STEP_PIN         26
#define E_DIR_PIN          28
#define E_ENABLE_PIN       24

#define Q_STEP_PIN         36
#define Q_DIR_PIN          34
#define Q_ENABLE_PIN       30
#else
//UNO config
#define PIN_F_DIR      2
#define PIN_F_STEP     3
#define PIN_B_DIR      4
#define PIN_B_STEP     5
#define PIN_L_DIR      6
#define PIN_L_STEP     7
#define PIN_R_DIR      8
#define PIN_R_STEP     9
#define PIN_D_DIR      10
#define PIN_D_STEP     11
#define PIN_U_DIR      12
#define PIN_U_STEP     13
#define PIN_DISABLE    A0
#endif

/**/
#define M_F 0
#define M_B 1
#define M_L 2
#define M_R 3
#define M_D 4
#define M_U 5

#define CCW     0
#define CW      1

/*
udlrfbBFRLDU
udlrfbudlrfbudlrfbudlrfbudlrfbudlrfbBFRLDUBFRLDUBFRLDUBFRLDUBFRLDUBFRLDU
udlrfbudlrfbBFRLDUBFRLDU
Cross pattern - RlRlUdUdfBfB
scramble/unscramble 
''.join(map( lambda a : random.choice( "udlrfbUDLRFB" ), range(25) ))
rLrddFlbdUUDfFudfbFUBRruf
FURrbufBFDUfFduuDBLfDDRlR
rLrddFlbdUUDfFudfbFUBRrufFURrbufBFDUfFduuDBLfDDRlR

scramble/descramble
blDbrrDbRBdffUfddFRurDFLbUrd
DRuBlfdRUrfDDFuFFDbrBdRRBdLB

both in one line
blDbrrDbRBdffUfddFRurDFLbUrd-DRuBlfdRUrfDDFuFFDbrBdRRBdLB

uf
udlrfb

uUdDlLrRfFbB
fluLF
fuF
buB
luL
ruR
buB
fl
fF
blDbrrDbRBd

fuluburuRuBuLuF
flbrRBLF
*/

int dirPinFromMotor( int motor ) {
    switch( motor ) {
        case M_F: return PIN_F_DIR;
        case M_B: return PIN_B_DIR;
        case M_L: return PIN_L_DIR;
        case M_R: return PIN_R_DIR;
        case M_D: return PIN_D_DIR;
        case M_U: return PIN_U_DIR;
    }
    return -1;
}

int stepPinFromMotor( int motor ) {
    switch( motor ) {
        case M_F: return PIN_F_STEP;
        case M_B: return PIN_B_STEP;
        case M_L: return PIN_L_STEP;
        case M_R: return PIN_R_STEP;
        case M_D: return PIN_D_STEP;
        case M_U: return PIN_U_STEP;
    }
    return -1;
}

bool motorsOnEh;

void motorsOn() {
#ifdef ARDUINO_AVR_MEGA2560
    digitalWrite(PIN_F_DISABLE, 0);
    digitalWrite(PIN_B_DISABLE, 0);
    digitalWrite(PIN_L_DISABLE, 0);
    digitalWrite(PIN_R_DISABLE, 0);
    digitalWrite(PIN_D_DISABLE, 0);
    digitalWrite(PIN_U_DISABLE, 0);
#else
    digitalWrite(PIN_DISABLE, 0);
#endif
}

void motorsOff() {
#ifdef ARDUINO_AVR_MEGA2560
    digitalWrite(PIN_F_DISABLE, 1);
    digitalWrite(PIN_B_DISABLE, 1);
    digitalWrite(PIN_L_DISABLE, 1);
    digitalWrite(PIN_R_DISABLE, 1);
    digitalWrite(PIN_D_DISABLE, 1);
    digitalWrite(PIN_U_DISABLE, 1);
#else
    digitalWrite(PIN_DISABLE, 1);
#endif
}

void motorsInit() {
    motorsOff();
#ifdef ARDUINO_AVR_MEGA2560
    pinMode(PIN_F_DISABLE, OUTPUT);
    pinMode(PIN_B_DISABLE, OUTPUT);
    pinMode(PIN_L_DISABLE, OUTPUT);
    pinMode(PIN_R_DISABLE, OUTPUT);
    pinMode(PIN_D_DISABLE, OUTPUT);
    pinMode(PIN_U_DISABLE, OUTPUT);
#else
    pinMode(PIN_DISABLE, OUTPUT);
#endif
}

int speed = 1;

#define STEPS_PER_090    50
#define STEPS_PER_180   100
#define INTER_STEP_DELAY    0

#include "delay_table.h"


void turn090( int motor, int dir ) {
    digitalWrite( dirPinFromMotor( motor ), dir );
    int stepPin = stepPinFromMotor( motor );
    for( int i = 0; i < STEPS_PER_090; i++ ) {
        digitalWrite( stepPin, 1 );
        digitalWrite( stepPin, 0 );
        delayMicroseconds( getDelay90(i) );
    }
    delay( getInterDelay() );
}

void turn180( int motor, int dir ) {
    digitalWrite( dirPinFromMotor( motor ), dir );
    int stepPin = stepPinFromMotor( motor );
    for( int i = 0; i < STEPS_PER_180; i++ ) {
        digitalWrite( stepPin, 1 );
        digitalWrite( stepPin, 0 );
        delayMicroseconds( getDelay180(i) );
    }
    delay( getInterDelay() );
}

void turn090_180( int motor1, int dir1, int motor2, int dir2 ) {
    digitalWrite( dirPinFromMotor( motor1 ), dir1 );
    digitalWrite( dirPinFromMotor( motor2 ), dir2 );

    int stepPin1 = stepPinFromMotor( motor1 );
    int stepPin2 = stepPinFromMotor( motor2 );
    for( int i = 0; i < STEPS_PER_180; i++ ) {
        if( i % 2 == 0 ) {//tricky part, only step half the time
            digitalWrite( stepPin1, 1 );
            digitalWrite( stepPin1, 0 );
        }
        digitalWrite( stepPin2, 1 );
        digitalWrite( stepPin2, 0 );
        delayMicroseconds( getDelay180(i) );
    }
    delay( getInterDelay() );
}

void turn180_090( int motor1, int dir1, int motor2, int dir2 ) {
    turn090_180( motor2, dir2, motor1, dir1 );
}

void turn180_180( int motor1, int dir1, int motor2, int dir2 ) {
    digitalWrite( dirPinFromMotor( motor1 ), dir1 );
    digitalWrite( dirPinFromMotor( motor2 ), dir2 );

    int stepPin1 = stepPinFromMotor( motor1 );
    int stepPin2 = stepPinFromMotor( motor2 );
    for( int i = 0; i < STEPS_PER_180; i++ ) {
        digitalWrite( stepPin1, 1 );
        digitalWrite( stepPin1, 0 );
        digitalWrite( stepPin2, 1 );
        digitalWrite( stepPin2, 0 );
        delayMicroseconds( getDelay180(i) );
    }
    delay( getInterDelay() );
}

void turn090_090( int motor1, int dir1, int motor2, int dir2 ) {
    digitalWrite( dirPinFromMotor( motor1 ), dir1 );
    digitalWrite( dirPinFromMotor( motor2 ), dir2 );

    int stepPin1 = stepPinFromMotor( motor1 );
    int stepPin2 = stepPinFromMotor( motor2 );
    for( int i = 0; i < STEPS_PER_090; i++ ) {
        digitalWrite( stepPin1, 1 );
        digitalWrite( stepPin1, 0 );
        digitalWrite( stepPin2, 1 );
        digitalWrite( stepPin2, 0 );
        delayMicroseconds( getDelay90(i) );
    }
    delay( getInterDelay() );
}


void setup() {
    //digitalWrite(PIN_U_STUPID_RESET_N, 1);
    //pinMode(PIN_U_STUPID_RESET_N,  OUTPUT);

    digitalWrite(PIN_F_DIR,  0);
    digitalWrite(PIN_F_STEP, 0);
    digitalWrite(PIN_B_DIR,  0);
    digitalWrite(PIN_B_STEP, 0);
    digitalWrite(PIN_L_DIR,  0);
    digitalWrite(PIN_L_STEP, 0);
    digitalWrite(PIN_R_DIR,  0);
    digitalWrite(PIN_R_STEP, 0);
    digitalWrite(PIN_D_DIR,  0);
    digitalWrite(PIN_D_STEP, 0);
    digitalWrite(PIN_U_DIR,  0);
    digitalWrite(PIN_U_STEP, 0);

    motorsInit();

    pinMode(PIN_F_DIR,  OUTPUT);
    pinMode(PIN_F_STEP, OUTPUT);
    pinMode(PIN_B_DIR,  OUTPUT);
    pinMode(PIN_B_STEP, OUTPUT);
    pinMode(PIN_L_DIR,  OUTPUT);
    pinMode(PIN_L_STEP, OUTPUT);
    pinMode(PIN_R_DIR,  OUTPUT);
    pinMode(PIN_R_STEP, OUTPUT);
    pinMode(PIN_D_DIR,  OUTPUT);
    pinMode(PIN_D_STEP, OUTPUT);
    pinMode(PIN_U_DIR,  OUTPUT);
    pinMode(PIN_U_STEP, OUTPUT);
    motorsOnEh = false;

    Serial.begin(115200);
    Serial.print( "+");
}



void loop() {
    char c;

    c = Serial.read();
    if( c < 0 ) return;

    switch( c ) {
        case 27:
            Serial.println( "Shutdown!");
            motorsOff();
            break;
        case ' ':
            if( motorsOnEh ) {
                Serial.println( "Off!");
                motorsOff();
                motorsOnEh = false;
            }
            else {
                Serial.println( "On!");
                motorsOn();
                motorsOnEh = true;
            }
            break;
        case '[':
            Serial.print( "[");
            motorsOn();
            motorsOnEh = true;
            break;
        case ']':
            Serial.print( "]");
            motorsOff();
            motorsOnEh = false;
            break;
#ifdef ARDUINO_AVR_MEGA2560
        case '!': Serial.println( "F motor enabled"); digitalWrite(PIN_F_DISABLE, 0); break;
        case '@': Serial.println( "B motor enabled"); digitalWrite(PIN_B_DISABLE, 0); break;
        case '#': Serial.println( "L motor enabled"); digitalWrite(PIN_L_DISABLE, 0); break;
        case '$': Serial.println( "R motor enabled"); digitalWrite(PIN_R_DISABLE, 0); break;
        case '%': Serial.println( "D motor enabled"); digitalWrite(PIN_D_DISABLE, 0); break;
        case '^': Serial.println( "U motor enabled"); digitalWrite(PIN_U_DISABLE, 0); break;
#endif

        case '1': speed = 1; Serial.print('1'); /*reportSpeedInfo();*/ break;
        case '2': speed = 2; Serial.print('2'); /*reportSpeedInfo();*/ break;
        case '3': speed = 3; Serial.print('3'); /*reportSpeedInfo();*/ break;
        case '4': speed = 4; Serial.print('4'); /*reportSpeedInfo();*/ break;
        case '5': speed = 5; Serial.print('5'); /*reportSpeedInfo();*/ break;
        case '6': speed = 6; Serial.print('6'); /*reportSpeedInfo();*/ break;
        case '7': speed = 7; Serial.print('7'); /*reportSpeedInfo();*/ break;
        case '8': speed = 8; Serial.print('8'); /*reportSpeedInfo();*/ break;
        case '9': speed = 9; Serial.print('9'); /*reportSpeedInfo();*/ break;


        //F/B
/*F   */case 'a': turn090       ( M_F,  CW           ); Serial.print('a'); break;
/*F2  */case 'b': turn180       ( M_F,  CW           ); Serial.print('b'); break;
/*F'  */case 'c': turn090       ( M_F, CCW           ); Serial.print('c'); break;
/*F B */case 'd': turn090_090   ( M_F,  CW, M_B,  CW ); Serial.print('d'); break;
/*F2B */case 'e': turn180_090   ( M_F,  CW, M_B,  CW ); Serial.print('e'); break;
/*F'B */case 'f': turn090_090   ( M_F, CCW, M_B,  CW ); Serial.print('f'); break;
/*  B */case 'g': turn090       (           M_B,  CW ); Serial.print('g'); break;
/*F B2*/case 'h': turn090_180   ( M_F,  CW, M_B,  CW ); Serial.print('h'); break;
/*F2B2*/case 'i': turn180_180   ( M_F,  CW, M_B,  CW ); Serial.print('i'); break;
/*F'B2*/case 'j': turn090_180   ( M_F, CCW, M_B,  CW ); Serial.print('j'); break;
/*  B2*/case 'k': turn180       (           M_B, CCW ); Serial.print('k'); break;
/*F B'*/case 'l': turn090_090   ( M_F,  CW, M_B, CCW ); Serial.print('l'); break;
/*F2B'*/case 'm': turn180_090   ( M_F,  CW, M_B, CCW ); Serial.print('m'); break;
/*F'B'*/case 'n': turn090_090   ( M_F, CCW, M_B, CCW ); Serial.print('n'); break;
/*  B'*/case 'o': turn090       (           M_B, CCW ); Serial.print('o'); break;

        //L/R
/*L   */case 'p': turn090       ( M_L,  CW           ); Serial.print('p'); break;
/*L2  */case 'q': turn180       ( M_L,  CW           ); Serial.print('q'); break;
/*L'  */case 'r': turn090       ( M_L, CCW           ); Serial.print('r'); break;
/*L R */case 's': turn090_090   ( M_L,  CW, M_R,  CW ); Serial.print('s'); break;
/*L2R */case 't': turn180_090   ( M_L,  CW, M_R,  CW ); Serial.print('t'); break;
/*L'R */case 'u': turn090_090   ( M_L, CCW, M_R,  CW ); Serial.print('u'); break;
/*  R */case 'v': turn090       (           M_R,  CW ); Serial.print('v'); break;
/*L R2*/case 'w': turn090_180   ( M_L,  CW, M_R,  CW ); Serial.print('w'); break;
/*L2R2*/case 'x': turn180_180   ( M_L,  CW, M_R,  CW ); Serial.print('x'); break;
/*L'R2*/case 'y': turn090_180   ( M_L, CCW, M_R,  CW ); Serial.print('y'); break;
/*  R2*/case 'z': turn180       (           M_R, CCW ); Serial.print('z'); break;
/*L R'*/case 'A': turn090_090   ( M_L,  CW, M_R, CCW ); Serial.print('A'); break;
/*L2R'*/case 'B': turn180_090   ( M_L,  CW, M_R, CCW ); Serial.print('B'); break;
/*L'R'*/case 'C': turn090_090   ( M_L, CCW, M_R, CCW ); Serial.print('C'); break;
/*  R'*/case 'D': turn090       (           M_R, CCW ); Serial.print('D'); break;

        //U/D
/*U   */case 'E': turn090       ( M_U,  CW           ); Serial.print('E'); break;
/*U2  */case 'F': turn180       ( M_U,  CW           ); Serial.print('F'); break;
/*U'  */case 'G': turn090       ( M_U, CCW           ); Serial.print('G'); break;
/*U D */case 'H': turn090_090   ( M_U,  CW, M_D,  CW ); Serial.print('H'); break;
/*U2D */case 'I': turn180_090   ( M_U,  CW, M_D,  CW ); Serial.print('I'); break;
/*U'D */case 'J': turn090_090   ( M_U, CCW, M_D,  CW ); Serial.print('J'); break;
/*  D */case 'K': turn090       (           M_D,  CW ); Serial.print('K'); break;
/*U D2*/case 'L': turn090_180   ( M_U,  CW, M_D,  CW ); Serial.print('L'); break;
/*U2D2*/case 'M': turn180_180   ( M_U,  CW, M_D,  CW ); Serial.print('M'); break;
/*U'D2*/case 'N': turn090_180   ( M_U, CCW, M_D,  CW ); Serial.print('N'); break;
/*  D2*/case 'O': turn180       (           M_D, CCW ); Serial.print('O'); break;
/*U D'*/case 'P': turn090_090   ( M_U,  CW, M_D, CCW ); Serial.print('P'); break;
/*U2D'*/case 'Q': turn180_090   ( M_U,  CW, M_D, CCW ); Serial.print('Q'); break;
/*U'D'*/case 'R': turn090_090   ( M_U, CCW, M_D, CCW ); Serial.print('R'); break;
/*  D'*/case 'S': turn090       (           M_D, CCW ); Serial.print('S'); break;


        default:
            break;
    }

}

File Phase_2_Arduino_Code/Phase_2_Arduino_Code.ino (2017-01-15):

#define X_STEP_PIN         54
#define X_DIR_PIN          55
#define X_ENABLE_PIN       38
#define X_MIN_PIN           3
#define X_MAX_PIN           2

#define Y_STEP_PIN         60
#define Y_DIR_PIN          61
#define Y_ENABLE_PIN       56
#define Y_MIN_PIN          14
#define Y_MAX_PIN          15

#define Z_STEP_PIN         46
#define Z_DIR_PIN          48
#define Z_ENABLE_PIN       62
#define Z_MIN_PIN          18
#define Z_MAX_PIN          19

#define E_STEP_PIN         26
#define E_DIR_PIN          28
#define E_ENABLE_PIN       24

#define Q_STEP_PIN         36
#define Q_DIR_PIN          34
#define Q_ENABLE_PIN       30

#define SOLENOID_EQ         9
#define SOLENOID_XY         8

//enum Side {
#define X       1
#define Y       2
#define E       4
#define Q       8
//};

#define CCW     0
#define CW      1

//enum Side { U, D, L, R, F, B };
//enum Dir { CW, CCW, CW2 };

//enum GrabAxis {
#define XY      1
#define EQ      2
#define BOTH    (XY|EQ)
//};

bool isEngaged;

bool debug = true;

unsigned char delays[400] = {
#include "delay_table.h"
};

#define DELAY_TBL_CNT   sizeof(delays)/sizeof(delays[0])

static int speed_scale=16;

template <int CNT>
int getDelay( int i ) {
    enum {
        RAMP_UP_END = DELAY_TBL_CNT,
        RAMP_DOWN_START = CNT - DELAY_TBL_CNT,
    };
    if( i < RAMP_UP_END ) {
        return delays[i];
    }
    else if( i < RAMP_DOWN_START ) {
        return delays[DELAY_TBL_CNT-1];
    }
    else {
        return delays[CNT-1-i];
    }
    return 50;
    //DELAY_TBL_CNT
}



void safetyShutdown() {
    digitalWrite(X_ENABLE_PIN, HIGH);
    digitalWrite(Y_ENABLE_PIN, HIGH);
    digitalWrite(X_ENABLE_PIN, HIGH);
    digitalWrite(E_ENABLE_PIN, HIGH);
    digitalWrite(Q_ENABLE_PIN, HIGH);
    digitalWrite( SOLENOID_EQ, LOW );
    digitalWrite( SOLENOID_XY, LOW );

    isEngaged = false;
    if( debug ) Serial.println("SHUTTIN DOWN!!");
}

int dirPin( int s ) {
    switch( s ) {
    case X: return X_DIR_PIN;
    case Y: return Y_DIR_PIN;
    case E: return E_DIR_PIN;
    case Q: return Q_DIR_PIN;
    }
    return -1;
}

int stepPin( int s ) {
    switch( s ) {
    case X: return X_STEP_PIN;
    case Y: return Y_STEP_PIN;
    case E: return E_STEP_PIN;
    case Q: return Q_STEP_PIN;
    }
    return -1;
}

void motorsOn(int sides = X | Y | E | Q ) {
    if( sides & X ) digitalWrite(X_ENABLE_PIN, LOW);
    if( sides & Y ) digitalWrite(Y_ENABLE_PIN, LOW);
    if( sides & E ) digitalWrite(E_ENABLE_PIN, LOW);
    if( sides & Q ) digitalWrite(Q_ENABLE_PIN, LOW);
    if( debug ) Serial.println("motorsOn()");
}

void motorsOff(int sides = X | Y | E | Q ) {
    if( sides & X ) digitalWrite(X_ENABLE_PIN, HIGH);
    if( sides & Y ) digitalWrite(Y_ENABLE_PIN, HIGH);
    if( sides & E ) digitalWrite(E_ENABLE_PIN, HIGH);
    if( sides & Q ) digitalWrite(Q_ENABLE_PIN, HIGH);
    if( debug ) Serial.println("motorsOff()");
}

void grab( int axis=BOTH) {
    //delay(100);
    if( axis & XY ) {
        digitalWrite( SOLENOID_XY, HIGH );
    }
    if( axis & EQ ) {
        digitalWrite( SOLENOID_EQ, HIGH );
    }
    //delay(100);
    if( debug ) Serial.println("grab()");
}

void ungrab( int axis=BOTH) {
    //delay(100);
    if( axis & XY ) {
        digitalWrite( SOLENOID_XY, LOW );
    }
    if( axis & EQ ) {
        digitalWrite( SOLENOID_EQ, LOW );
    }
    //delay(100);
    if( debug ) Serial.println("ungrab()");
}

void toggleEngage() {
    if( isEngaged ) {
        ungrab();
        motorsOff();
        isEngaged = false;
    }
    else {
        grab();
        delay( 50 );
        motorsOn();
        isEngaged = true;
    }
    if( debug ) Serial.println("toggleEngage()");
}


#define STEP_N(deg) (int)(50.0*16.0*(float)deg/90.0)
#define STEP_45     STEP_N(45)
#define STEP_90     STEP_N(90)
#define STEP_180    STEP_N(180)

void stepMotors( int sides, int cnt ) {
    int sidesVec[4];
    int sidesCnt;
    sidesCnt = 0;
    if( sides & X ) { sidesVec[ sidesCnt++ ] = X_STEP_PIN; }
    if( sides & Y ) { sidesVec[ sidesCnt++ ] = Y_STEP_PIN; }
    if( sides & E ) { sidesVec[ sidesCnt++ ] = E_STEP_PIN; }
    if( sides & Q ) { sidesVec[ sidesCnt++ ] = Q_STEP_PIN; }
    for( int i = 0; i < cnt; i++ ) {
        int idx = i < 800 ? i : 799;

        for( int j = 0; j < sidesCnt; j++ ) {
            digitalWrite(sidesVec[j], HIGH);
        }
        for( int j = 0; j < sidesCnt; j++ ) {
            digitalWrite(sidesVec[j], LOW);
        }
        //delayMicroseconds( delays[idx] );
        delayMicroseconds( 100 );
    }
    if( debug ) Serial.println("stepMotors()");
}


void setDirs( int sides, int ccwDirSides ) {
    if( sides & X ) { if( ccwDirSides & X ) { digitalWrite( X_DIR_PIN, CCW ); } else { digitalWrite( X_DIR_PIN, CW ); } }
    if( sides & Y ) { if( ccwDirSides & Y ) { digitalWrite( Y_DIR_PIN, CCW ); } else { digitalWrite( Y_DIR_PIN, CW ); } }
    if( sides & E ) { if( ccwDirSides & E ) { digitalWrite( E_DIR_PIN, CCW ); } else { digitalWrite( E_DIR_PIN, CW ); } }
    if( sides & Q ) { if( ccwDirSides & Q ) { digitalWrite( Q_DIR_PIN, CCW ); } else { digitalWrite( Q_DIR_PIN, CW ); } }
}

#define OVERSHOOTCNT        400
#define TURN90CNT           1600
#define TURN90WOVERSHOT     (TURN90CNT+OVERSHOOTCNT)

void fast90Motors( int sides, int ccwDirSides ) {
    int sidesVec[4];
    int sidesCnt;
    sidesCnt = 0;

    setDirs( sides, ccwDirSides );
    if( sides & X ) { sidesVec[ sidesCnt++ ] = X_STEP_PIN; }
    if( sides & Y ) { sidesVec[ sidesCnt++ ] = Y_STEP_PIN; }
    if( sides & E ) { sidesVec[ sidesCnt++ ] = E_STEP_PIN; }
    if( sides & Q ) { sidesVec[ sidesCnt++ ] = Q_STEP_PIN; }

    for( int i = 0; i < TURN90CNT; i++ ) {
        for( int j = 0; j < sidesCnt; j++ ) { digitalWrite(sidesVec[j], HIGH ); }
        for( int j = 0; j < sidesCnt; j++ ) { digitalWrite(sidesVec[j], LOW  ); }
        delayMicroseconds( getDelay<TURN90CNT>(i)*speed_scale );
    }
    if( debug ) Serial.println("fast90Motors()");
}
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

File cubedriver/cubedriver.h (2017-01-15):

#pragma once
#include "util.h"
#include "capv4l2.h"
#include "serial.h"

#include "threaded_solver2.h"

typedef std::unique_ptr<CapV4L2> CapV4L2Ptr;

struct PerCam{
    CapV4L2Ptr           cap;
    SDL_Rect             srec; 
    SDL_Rect             drec; // where to render this in the window
    boost::optional<int> exposureAbsolute;
    boost::optional<int> whiteBalanceTemperature;
    boost::optional<int> gain;
    PerCam( std::string const &dev, int xres, int yres, boost::optional<int> exposureAbsolute, boost::optional<int> whiteBalanceTemperature, boost::optional<int> gain );
};

typedef std::unique_ptr<SerialNonBlocking> SerialPtr;

struct Inst{
    enum Op{
        Send,       // send STR to serial port
        Expect,     // wait until STR received from serial port
        WaitMicros, // wait for N microseconds before next instruction
        SnapCal,    // snap calibrationColors using calibrationStates[N]
        ValidateCal,// validate state against calibrationStates[N]
        SaveCal,    // save calibrationColors to disk
        Solved, 
    };
    Op          op;   // operator
    std::string str;  // string operand
    int         n;    // integer operand
};

struct App{
    ThreadedSolver        threadedSolver;
    
    SDLInitAndQuit        sdlinitAndQuit;
    TTFInitAndQuit        ttfInitAndQuit;

    SerialPtr             ser;
    std::string           serRcv;

    char                  solveSpeed = '3';
    char                  calSpeed   = '3';
    unsigned long         targetMS = 980;
    
    std::vector<Inst>     program;
    size_t                programCounter=0;
    std::string           programRcvExpected;
    unsigned long         programTimeExpected=0;
    
    void continueProgram(bool running);
    bool isRunning()const{ return programCounter<program.size(); }

    void runProgram(std::vector<Inst> const &pgm){
        if(!isRunning()){
            program = pgm;
            programCounter = 0;
            continueProgram(true);
        }
    }
    
    unsigned long     autoSolveArmTime=0;
    unsigned long     elapsedSolveTime=0;
    unsigned long     movesStartedTime=0;
    
    std::vector<Inst> getCalibrationProgram()const;
    std::vector<Inst> getCalibrationTestProgram()const;
    std::vector<Inst> getMovesProgram(std::string const &moves)const;
    std::vector<Inst> getURFProgram()const;
    std::vector<Inst> getUFLProgram()const;
    std::vector<Inst> getScrambleProgram()const;
    std::vector<Inst> getSolveProgram()const;
    std::vector<Inst> getAutoSolveProgram()const;
    
    std::string           lastSolution;
    
    void serWrite( std::string const &str ){
        if(ser){
            ser->write(str);
        }
    }
    
    // 6 colors for each position ( centers are represented but ignored )
    SDL_Color             calibrationColors[54][6];
    bool                  validateCalMismatch[54][6];
    
    std::vector< PerCam > cams;

    int                   threads      = 2;
    int const             border       = 8;
    int                   xres         = 160;
    int                   yres         = 120;
    int                   previewScale = 2;
    int                   cursorRadius = 4; // square radius in camera pixels ( radius 2 = 5x5 )
    
    void camPointToPreviewPoint(SDL_Rect const &drec, int &x, int &y){
        x = x*previewScale + drec.x;
        y = y*previewScale + drec.y;
    }
    
    SDL_WindowPtr         win;
    SDL_RendererPtr       ren;
    
    SDL_TexturePtr        texPreview;
    
    TTF_FontPtr           fonMono;
    TTF_FontPtr           fonTimer;
    
    struct Text{
        TTF_Font       *fon = nullptr;
        SDL_Color       clr;
        SDL_TexturePtr  tex;
        SDL_Rect        rec = {0,0,0,0};
        std::string     text;
        bool            changed=false;
    };
    std::vector<Text>     texts;
    
    SDL_Rect              faceletMapEdit[54];
    SDL_Rect              faceletMapEditBoundary;

    SDL_Rect              faceletMapMatched[54];
    SDL_Rect              faceletMapMatchedBoundary;

    
    int                   selectedFacelet = -1;
    int                   selectedCursor  = -1;
    int                   selectedExposureControl = -1;
    
    struct Cursor{
        int facelet=-1;
        int camera=-1;
        int x=-1;
        int y=-1;
        int radius = -1;
        boost::optional<int> associatedCursor;  // only for center facelets, defines which cursor's calibration column to use
    };
    bool haveCenterCursors = false;
    bool suspendCenters = false;
    bool const useCenters()const{ return haveCenterCursors && !suspendCenters; }
    
    typedef std::vector<Cursor> Cursors;
    Cursors               cursors;
    
    SDL_Color faceletColors[54]; // average of 9x9 pixels cetered under cursor
    int faceletStates[54];       // -1 for unknown ( if cursor not defined or calibration not run )
    int prevFaceletStates[54];
    
    void assignAssociatedCursorsForCenters();
    
    // find index of closest match to faceletColor in calibrationColors[facelet][]
    //   return -1 if none of the colors calibrationColors[facelet][] have been assigned yet
    template <class DISTFUNC>
    int findClosestCalibrationColor(int facelet, SDL_Color const &faceletColor,DISTFUNC distfunc);
    void analyzeColors(); 

    std::string configFilename;
    
    App(std::string const &configFilename);
    void load(std::string const &filename);
    void save(std::string const &filename);
    void loadCal(std::string const &filename);
    void saveCal(std::string const &filename);
    
    void setupFaceletMap(SDL_Point where, unsigned scale, unsigned gap, /*out*/SDL_Rect faceletMap[54], /*out*/SDL_Rect &boundary);
    
    // 0-53, -1 for no hit
    int hitTestFaceletMap(SDL_Point where);
    
    // 0-cams.size()-1, -1 for no hit
    //   outCamPoint set to location  within camera
    int hitTestPreview(SDL_Point where, SDL_Point &outCamPoint);
    
    void moveCursor(int dx, int dy);
    
    void run();
    void loop();    
    void renderAll();
    
    void renderPreview( PerCam &cam );
    void renderFaceletMapEdit();
    void renderFaceletMapMatched();
    void renderCalibrationColors();

    void renderCursor( Cursor const &cur, SDL_Color const &clr, bool faceletSelected, bool cursorSelected );
    
    SDL_Color cursorColor( Cursor const &cur );
    
    void clearText(unsigned row);
    void printText(unsigned row, char const *fmt, ...);
    
    void makeText(unsigned row);

    void onKeyDown(SDL_Keycode sym, Uint16 mod);
    void onKeyUp(SDL_Keycode sym, Uint16 mod);
    void onLButtonDown(int mX, int mY);
    void onLButtonUp(int mX, int mY);
    void onRButtonDown(int mX, int mY);
    void onRButtonUp(int mX, int mY);
};

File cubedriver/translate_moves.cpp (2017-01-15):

#include <string>
#include <stdexcept>

namespace{
    int const U_ = 0;
    int const R_ = 1;
    int const F_ = 2;
    int const D_ = 3;
    int const L_ = 4;
    int const B_ = 5;
}

// move ( or pair of opposite face moves )
struct Move{
    int  face1  = -1; // one of U_, L_ or F_ ( or -1 if none )
    int  times1 =  0; // 0=None, 1=CW, 2=180, 3=CCW 
    int  face2  = -1; // one of R_, D_, or B_ ( or -1 if none )
    int  times2 =  0; // 0=None, 1=CW, 2=180, 3=CCW 
    
    bool empty() const { return times1 <= 0 && times2 <= 0; }
    bool clear() { face1 = -1; times1 = 0; face2 = -1; times2 = 0; }
    
    Move() {}
    Move( int face1, int times1, int face2, int times2 )
        : face1(face1), times1(times1), face2(face2), times2(times2)
    {
    }
    Move( int face, int times ){
        switch(face){
        case U_: case L_: case F_:
            face1  = face;
            times1 = times;
            break;
        case R_: case D_: case B_:
            face2  = face;
            times2 = times;
            break;
        }        
    }
};

inline bool operator==(Move const &l, Move const &r){
    return // allow match based on times==0 regardless of face
        ( l.times1 == r.times1 && ( l.times1 == 0 || l.face1  == r.face1 ) ) &&
        ( l.times2 == r.times2 && ( l.times2 == 0 || l.face2  == r.face2 ) ) ;
}

// combines r into l if possible, and returns true
//  returns false ( and leaves both r and l unchanged ) if r can't be combined into l
inline bool combineMoves(Move &l, Move const &r){
    // l.face1 not compatible with r.face1 ( both defined but not equal )
    if( l.times1 > 0 && r.times1 > 0 && l.face1 != r.face1 ) return false;
    // l.face1 not compatible with r.face1 ( both defined but not equal )
    if( l.times2 > 0 && r.times2 > 0 && l.face2 != r.face2 ) return false;
    // l.face1 not compatible with r.face2 ( both defined but not opposite )
    if( l.times1 > 0 && r.times2 > 0 && ( l.face1 % 3 ) != ( r.face2 % 3 ) ) return false;
    // l.face2 not compatible with r.face1 ( both defined but not opposite )
    if( l.times2 > 0 && r.times1 > 0 && ( l.face2 % 3 ) != ( r.face1 % 3 ) ) return false;

    // combine r.face1 into l.face1
    if( l.times1 <= 0 ){  // l.face1 not defined:
        // just take r.face1 ( which may also be undefined )
        l.face1  = r.face1;
        l.times1 = r.times1;
    }
    else if( r.times1 > 0 ){ // l.face1 and r.face1 both defined
        // add rotations
        l.times1 = (l.times1 + r.times1) % 4;
        if( l.times1 == 0 ){
            l.face1 = -1; // canonical form of no rotation has no face
        }
    }
    //else: r.face1 not defined, leave l.face1 alone
    
    if( l.times2 <= 0 ){  // l.face2 not defined:
        // just take r.face2 ( which may also be undefined )
        l.face2  = r.face2;
        l.times2 = r.times2;
    }
    else if( r.times2 > 0 ){ // l.face2 and r.face2 both defined
        // add rotations
        l.times2 = (l.times2 + r.times2) % 4;
        if( l.times2 == 0 ){
            l.face2 = -1; // canonical form of no rotation has no face
        }
    }
    //else: r.face2 not defined, leave l.face2 alone

    return true;
}


// table to translate a Move ( including double move ) into a single byte command for the machine
std::pair<Move,char> const moveAndCmd[] = {
    { { F_,  1, -1,  0 }, 'a' },
    { { F_,  2, -1,  0 }, 'b' },
    { { F_,  3, -1,  0 }, 'c' },
    { { F_,  1, B_,  1 }, 'd' },
    { { F_,  2, B_,  1 }, 'e' },
    { { F_,  3, B_,  1 }, 'f' },
    { { -1,  0, B_,  1 }, 'g' },
    { { F_,  1, B_,  2 }, 'h' },
    { { F_,  2, B_,  2 }, 'i' },
    { { F_,  3, B_,  2 }, 'j' },
    { { -1,  0, B_,  2 }, 'k' },
    { { F_,  1, B_,  3 }, 'l' },
    { { F_,  2, B_,  3 }, 'm' },
    { { F_,  3, B_,  3 }, 'n' },
    { { -1,  0, B_,  3 }, 'o' },
    { { L_,  1, -1,  0 }, 'p' },
    { { L_,  2, -1,  0 }, 'q' },
    { { L_,  3, -1,  0 }, 'r' },
    { { L_,  1, R_,  1 }, 's' },
    { { L_,  2, R_,  1 }, 't' },
    { { L_,  3, R_,  1 }, 'u' },
    { { -1,  0, R_,  1 }, 'v' },
    { { L_,  1, R_,  2 }, 'w' },
    { { L_,  2, R_,  2 }, 'x' },
    { { L_,  3, R_,  2 }, 'y' },
    { { -1,  0, R_,  2 }, 'z' },
    { { L_,  1, R_,  3 }, 'A' },
    { { L_,  2, R_,  3 }, 'B' },
    { { L_,  3, R_,  3 }, 'C' },
    { { -1,  0, R_,  3 }, 'D' },
    { { U_,  1, -1,  0 }, 'E' },
    { { U_,  2, -1,  0 }, 'F' },
    { { U_,  3, -1,  0 }, 'G' },
    { { U_,  1, D_,  1 }, 'H' },
    { { U_,  2, D_,  1 }, 'I' },
    { { U_,  3, D_,  1 }, 'J' },
    { { -1,  0, D_,  1 }, 'K' },
    { { U_,  1, D_,  2 }, 'L' },
    { { U_,  2, D_,  2 }, 'M' },
    { { U_,  3, D_,  2 }, 'N' },
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
};
size_t const moveAndCmdSize = sizeof(moveAndCmd)/sizeof(moveAndCmd[0]);

int faceFromChar(char c){
    switch(c){
    case 'U': return U_;
    case 'R': return R_;
    case 'F': return F_;
    case 'D': return D_;
    case 'L': return L_;
    case 'B': return B_;
    }
    return -1; // no face
}
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
